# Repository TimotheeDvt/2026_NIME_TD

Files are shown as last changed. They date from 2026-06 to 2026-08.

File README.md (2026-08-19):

REMORA logo
# Remora - A Motion-Controlled Musical Instrument

**Remora** is a digital musical instrument built around a martial arts staff (bô) augmented with an IMU sensor. Physical gestures such as spinning, tilting, striking, sweeping are translated in real time into expressive audio synthesis. The name *NIME* in the codebase stands for **New Instrument for Musical Expression**, and reflects the instrument design philosophy.

The audio side ships as **REMORA** (*Real-time Expressive Motion to Output Routing Audio*), a JUCE plugin that turns the incoming motion stream into sound.

---

## Project Overview

The instrument consists of two parts:

**Firmware** - An ESP32-S2 microcontroller mounted on the staff reads a 9-DOF IMU (MPU-9250) at 100 Hz and streams orientation data (quaternion, accelerometer, gyroscope, magnetometer) over Wi-Fi as OSC packets.

**Software** - REMORA, a JUCE-based VST3/Standalone audio plugin, receives the OSC stream, applies a user-defined calibration, extracts musical parameters from the motion, and drives an internal additive synthesiser with multiple mapping strategies selectable at runtime.

The two communicate over a local Wi-Fi network using UDP/OSC on port 8000.

```
[ Bô Staff ]
  └─ MPU-9250 IMU
  └─ SparkFun ESP32-S2 Thing+
       │  Wi-Fi / UDP / OSC  (port 8000)
       ▼
[ Host Computer ]
  └─ REMORA Plugin (VST3 / Standalone)
       ├─ OscReceiverManager   - receives and parses packets
       ├─ REMORAProcessor      - calibration, quaternion maths
       ├─ BoStaffSynth         - 4-voice additive synthesiser
       └─ IMappingStrategy     - swappable gesture-to-sound mappings
```

---

## Repository Structure

```
.
├── firmware/               # PlatformIO project for the ESP32-S2
│   ├── README.md               # Board/wiring, build/flash steps, OSC wire protocol
│   ├── platformio.ini          # Board, platform, and library config
│   └── src/
│       └── main.cpp            # IMU read loop + OSC transmission
│
├── software/               # JUCE CMake project (VST3 + Standalone)
│   ├── CMakeLists.txt
│   ├── Makefile                # Convenience wrapper around CMake
│   ├── README.md                # Build/run steps, calibration, and a deep dive into every mapping strategy's DSP
│   ├── IDEAS.md                # Scratchpad of in-progress mapping ideas
│   ├── JUCE/                   # JUCE library (cloned locally, not tracked here)
│   ├── Assets/
│   │   └── logo.svg
│   └── Source/
│       ├── PluginProcessor.{h,cpp}   # REMORAProcessor: calibration, OSC bridge
│       ├── PluginEditor.{h,cpp}      # REMORAEditor: main UI
│       ├── DATA/
│       │   ├── IMUData.h             # Lock-free IMU data store (seqlock)
│       │   └── OrientationPoint.h    # Timestamped quaternion for trail rendering
│       ├── DSP/
│       │   ├── MathHelpers.h         # Quaternion / vector maths
│       │   ├── IMappingStrategy.h    # Abstract mapping interface
│       │   ├── BoStaffSynth.{h,cpp}  # 4-voice additive synth engine
│       │   └── Mappings/             # One class per mapping strategy (see below)
│       ├── OSC/
│       │   └── OscReceiverManager.{h,cpp} # JUCE OSCReceiver wrapper
│       └── UI/                       # Calibration overlay, raw-data/debug/DSP
│                                     # diagnostic windows, spectrum analyser, styling
├── hardware/
│   ├── README.md                         # Casing model, printing, and battery notes
│   ├── Assets/                           # Reference models for the ESP32 board and MPU chip
│   ├── PRINTABLE/                        # Exported STL/gcode ready to slice and print
│   ├── case_vscode.scad                  # Parametric casing model (OpenSCAD Customizer)
│   └── base_print.scad                   # Utility to export a flat cutting/drilling pattern
│
└── tests/                   # OSC + gesture-mapping prototyping and test tools
    ├── testOSCReceiver.py                    # Minimal Python OSC listener on port 8000
    ├── exploration_tests/                    # PyQt/matplotlib gesture-simulation sandbox
    ├── PlugData/                             # Pure Data patches + mock-data generator
    └── PurrData/Karplus-Strong/              # Karplus-Strong string synthesis patches
```

---

## Firmware

ESP32-S2 + MPU-9250 read loop, streaming orientation/motion data as OSC over Wi-Fi. See [`firmware/README.md`](firmware/README.md) for wiring, configuration, build/flash steps, and the full OSC wire protocol.

---

## Software

JUCE VST3/Standalone plugin with a visual node-graph mapping engine. See [`software/README.md`](software/README.md) for build steps, running the plugin, calibration, the Node Graph Editor, and a full technical breakdown of every mapping strategy (Simple, Bowed Chord, Lead + Drone, Spin Filter, Martial Effort/Momentum, Azimut and its variants, Speed Gate, Spin Voices).

---

## Hardware

Staff-mounted enclosure carrying the ESP32-S2, MPU-9250, and a 2000 mAh LiPo battery (charged over USB via the board's onboard circuit). See [`hardware/README.md`](hardware/README.md) for the casing model and battery notes.

---

## Credits

Instrument design, firmware, and software by **Timothée D.**.

Built with [JUCE](https://juce.com/), [PlatformIO](https://platformio.org/), [hideakitai/MPU9250](https://github.com/hideakitai/MPU9250), and [CNMAT/OSC](https://github.com/CNMAT/OSC).

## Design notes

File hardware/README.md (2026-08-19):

REMORA logo
# REMORA Hardware
### Real-time Expressive Motion to Output Routing Audio

The staff-mounted enclosure that carries the ESP32-S2, MPU-9250, and battery. See the [top-level README](../README.md) for how this fits into the full system, and [firmware/README.md](../firmware/README.md) for the electronics wiring (I2C pins, charging circuit) that this case is built around.

## Contents

```
hardware/
├── Assets/                # Reference STL models for the ESP32 board and MPU chip
├── PRINTABLE/              # Exported STL/gcode ready to slice and print
├── case_vscode.scad        # Parametric casing model (OpenSCAD Customizer)
├── base_print.scad         # Utility to export a flat cutting/drilling pattern
└── calibration_stand.scad  # Stand used for the plugin's three-pose calibration procedure
```

## Enclosure

`case_vscode.scad` is a parametric OpenSCAD model of the staff-mounted enclosure for the ESP32-S2, MPU-9250, and a 2000 mAh LiPo battery, closed with a strap-and-screw fit. Customizer variables live at the top of the file; `render_mode` switches between rendering the cap, the base, both, or neither for faster iteration.

`base_print.scad` projects the base down to a flat pattern for cutting/drilling references.

Ready-to-slice output lives in `PRINTABLE/` (`BASE.stl`, `CAP.stl`).

## Battery

The SparkFun ESP32-S2 Thing+ has an onboard LiPo charge circuit with a JST-PH connector: connect the battery to the board and USB charges it directly, so the only cable the performer needs between sets is for charging - no separate charger required. Battery runtime under REMORA's actual 100 Hz sampling load has not been measured yet.

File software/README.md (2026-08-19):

REMORA logo
# REMORA Plugin
### Real-time Expressive Motion to Output Routing Audio

A real-time, dynamic **JUCE-based audio application** engineered to receive incoming multi-sensor IMU data via **Open Sound Control (OSC)**. The software serves as a modular audio mapping engine, converting spatial movements and hardware interactions into complex sound synthesis.

## Core Features

* **Standalone Application:** Ships today as a standalone desktop app; JUCE's plugin formats (VST3, AU, ...) are just a `FORMATS` entry away in `CMakeLists.txt` if a hosted-in-a-DAW build is ever needed.
* **Visual Node Graph Editor:** Every mapping - built-in or your own - is a `NodeGraph`: a DAG of Source/Math/Sink nodes evaluated once per audio block. Open the DSP window's **Graph** tab to inspect, rewire, or build one from scratch on a live patching canvas, with instant audio feedback and no recompiling required.
* **Preset Management:** Create, save, and load node graphs as presets from a preset folder you configure once (via the **Options** button) and that persists across sessions - your own patches live right alongside the built-in mappings.
* **Integrated Synth Engine:** Features a built-in algorithmic synthesis framework (`BoStaffSynth`) designed specifically for performance interaction.
* **Visual Diagnostic Windows:** Includes dedicated GUI interfaces for viewing live raw IMU data streams, debugging console logs, and visually monitoring spatial movements.
* **Scalable Branding:** The editor header renders the REMORA logo from an embedded SVG (`Assets/logo.svg`), tinted to match the UI palette, so it stays crisp at any window size instead of scaling a bitmap.

---

## Building

### Prerequisites

- **CMake 3.22+**
- **Ninja** build system
- A C++17-capable compiler (MSVC 2022 on Windows, Clang/GCC on macOS/Linux)
- JUCE cloned as a subdirectory at `JUCE/`

  ```bash
  cd software
  git clone https://github.com/juce-framework/JUCE.git
  ```

### Steps

Using the provided `Makefile`:

```bash
cd software
make clean    # remove build directory
make          # configure + build
make build    # build only
```

Build artefacts are written to `build/REMORA_artefacts/Standalone/REMORA` - run directly, no DAW needed.

Only the `Standalone` format is built right now (see `FORMATS` in `CMakeLists.txt`). Adding `VST3` (or another JUCE plugin format) to that list and rebuilding is enough to get a loadable plugin alongside it - no other code changes required.

### Runtime Dependencies

The app is dynamically linked so you might need to install some system librairies:

```bash
# Debian/Ubuntu
sudo apt install libfontconfig1 libfreetype6 libasound2

# Arch
sudo pacman -S fontconfig freetype2 alsa-lib
```

`fontconfig`, `freetype2`, and `alsa-lib` (ALSA) are the ones most likely to be missing on a minimal install; the rest (libstdc++, libpng, zlib, ...) ship on virtually every desktop system.

---

## Running

1. Ensure the ESP32 is streaming to your machine (or use `../tests/testOSCReceiver.py` to verify packets are arriving on port 8000). See [firmware/README.md](../firmware/README.md) for flashing the board.
2. Launch the standalone app.
3. Click **CONNECT** to start the OSC receiver on port 8000.
4. Click **CALIBRATE** and follow the three-pose procedure below to align the sensor's local frame with musical space.
5. Select a mapping from the dropdown and move the staff. Use **RAW DATA**, **DEBUG**, and **DSP** to open the diagnostic windows if needed.

### Calibration

The plugin uses a three-pose calibration to build a correction quaternion that maps the sensor's arbitrary mounting orientation to a consistent musical frame:

1. **Pose A** - staff horizontal, pointing forward
2. **Pose B** - staff vertical, pointing up
3. **Pose C** - staff horizontal, pointing right

After recording all three poses the plugin computes an orthonormal rotation matrix via polar decomposition and converts it to a quaternion applied to every subsequent reading. This means the instrument behaves identically regardless of how the sensor is physically oriented or mounted on the staff.

---

## Node Graph Editor

At the heart of REMORA's mapping engine is a **visual, node-based patching system**. Instead of hardcoded mapping classes, every performance mapping - from the simplest pitch/roll patch to the full Azimut engine - is a `Graph::NodeGraph`: a directed acyclic graph of small typed nodes, wired together and re-evaluated once per audio block.

* **Node Categories:**
  * **Source nodes** read live sensor/motion data (raw IMU channels, or derived motion features like gyroscopic magnitude, Laban weight/time/space/flow, facing angle, spin count).
  * **Math nodes** transform values in between - scaling, quantizing to a scale, gating, smoothing, crossfading, and more.
  * **Sink nodes** write the final result into a synth parameter (pitch, gain, filter cutoff, drive, reverb send, etc.), and automatically get a live-value monitor knob in the DSP window.
* **Live Patching Canvas:** Right-click empty canvas to add a node, drag from an output pin to an input pin to connect, right-click a node to delete it, right-click a wire to disconnect it. Pan by dragging the background, zoom with the mouse wheel. Hovering a pin shows its current live output value.
* **Auto Layout:** One click tidies the whole graph into ranked columns (flow direction) and lanes (parallel branches), with adjustable **Rank Sep** / **Node Sep** spacing sliders.
* **Non-Destructive Editing:** Edits are tracked per-graph; a **Reset Changes** button reverts the currently open graph back to how it looked when it was last loaded or saved, so experimenting with a built-in preset is always safe to undo.
* **Preset Workflow:** The selector bar above the canvas manages presets directly:
  * **New** starts a blank graph under a name you choose.
  * **Save** writes the current graph back to its file;
  * **Load** lists every `.xml` preset found in your preset folder and opens the one you pick.
  * **Options** lets you point the preset folder at any location on disk - the choice is remembered across sessions.

Because every mapping in this project - including all of the ones documented below - is implemented as a graph, none of them are fixed in stone: open any preset in the Graph tab to see exactly how it works, tweak it, or use it as the starting point for your own.

---

## Performance Mapping Strategies

This technical section details how physical movements stream through each mapping's node graph and directly manipulate the parameters of the synthesizer engine. Nine presets are currently registered in `SynthManager`, in the order below - every one of them a `NodeGraph` you can open, study, and remix in the [Node Graph Editor](#node-graph-editor).

| Mapping | Core idea |
|---|---|
| **Simple (Pitch+Roll)** | Single sine wave. Pitch angle sets the root frequency, roll amount sets the volume - the most direct staff-to-pitch mapping. |
| **Wind Noise** | No pitch, no chord - just filtered noise. Gyro+accel energy swells and dies down like gusts of wind, opening the noise filter and master lowpass brighter the faster you move. |
| **Bowed Chord** | Pitch angle quantizes to a chromatic root; yaw and roll select the chord voicing. Gyro speed acts like bow pressure, driving volume/drive/brightness, and sharp jabs add a noise strike. |
| **Lead + Drone** | Tilt drives a major-scale melody. A 4-voice drone chord stays harmonically locked below it; yaw crossfades two drone voices. |
| **Martial Momentum** | Root note is one of four fixed pitches chosen by spin plane/direction, gliding at a rate set by spin momentum. Volume is gated by movement plus Laban "Weight" and thrust jabs. |
| **Azimut Kinetic** | Root note from spin plane, direction, and facing (north/south). A single rotation-speed value fans out to filter cutoff, brightness, drive, noise, vibrato/tremolo and reverb all at once. |
| **Speed Gate** | Speed-gated crossfade: a simple pentatonic melody below a speed threshold, the full Azimut Kinetic mapping above it, with no clicks at the transition. |
| **Spin Voices (Scale)** | Roll angle selects which of 4 independent voices is "live"; its pitch snaps to the nearest note of a major scale and glides, while the other voices hold their last pitch/gain. |
| **Vocal Tract** | A physically-modeled voice (glottal source + digital-waveguide vocal tract) instead of the additive engine. Pitch sets glottal pitch, roll/yaw shape the vowel, motion and Laban "Weight" drive volume/tenseness, thrust jabs pinch the tract for consonant-like bursts. |

> Older presets (`Spin Filter`, `Martial Effort`, `Azimut`, `Azimut+`, `Azimut Reverb`, plain `Spin Voices`) still exist as `Graph::Presets::build*()` functions but are commented out of `SynthManager`'s registration list, superseded by the entries above - see [`Source/DSP/SynthManager.cpp`](Source/DSP/SynthManager.cpp).

---

### 1. Simple Mapping

* **Movement Inputs:** Absolute pitch tilt, absolute roll.
* **DSP Transformation:**
  * **Pitch Tilt:** Linearly maps pitch angle onto a single voice's fundamental frequency (100 Hz - 1000 Hz).
  * **Roll Gate:** Absolute roll angle drives master volume (0.05 - 0.20), acting as a simple tilt-based dynamic gate. A single voice plays with no partials beyond the fundamental.

---

### 2. Bowed Chord Mapping

* **Movement Inputs:** Total Gyroscopic Velocity ($|Gyro|$), Absolute Yaw, Pitch, and Roll ($|\text{Roll}|$).
* **DSP Transformation:**
  * **Excitation (The Bow):** Synthesizer excitement and voice gains are scaled by gyroscopic magnitude above a floor of $12.0^\circ/\text{s}$. If the device stops, the sound dampens instantly.
  * **Chord Harmonization:** Yaw angle selects 1 of 4 chords. Tilting the device past an intense roll boundary ($>0.7\text{ rad}$) overrides the scale into secondary chord sets.
  * **Acoustic Friction & Strikes:** Linear acceleration changes ($\Delta Accel$) generate an impulse envelope ($0.9990$ decay half-life) triggering a physical modeling-style noise stroke. Absolute roll maps to vibrato depth and high Z-axis angular velocity adds dynamic tremolo.

---

### 3. Lead + Drone Mapping

* **Movement Inputs:** Absolute Pitch (lead melody), Absolute Yaw (drone balance), Linear Acceleration Magnitude, Gyroscopic Magnitude.
* **DSP Transformation:**
  * **Lead Voice:** Pitch is quantized to a Major scale spanning several octaves around A3 ($220\text{ Hz}$).
  * **Locked Drone Voices:** Three drone voices sit at fixed intervals below the lead (an octave, two octaves, and a fifth) but are transposed by the *same* amount as the lead root, so they stay harmonically locked to whichever scale degree is currently playing.
  * **Timbre & Swell:** Acceleration magnitude drives lead voice gain, drone "swell" (amplitude growth), drive amount, noise injection, and upper-partial brightness. Yaw crossfades gain and hard-pans the two side drone voices against each other.

---

### 4. Spin Filter Mapping

* **Movement Inputs:** Gyroscopic Magnitude, Pitch, Yaw, Roll, Linear Acceleration Magnitude.
* **DSP Transformation:**
  * **Quantized Steps:** Gyroscopic magnitude steps through a 5-note Pentatonic Scale (2 voices: root + perfect fifth), rooted at C3 ($130.81\text{ Hz}$).
  * **Roll as Brightness Ceiling:** Absolute roll acts as a movable low-pass "ceiling" over the 6 harmonic partials - as roll increases, partials progressively unmute with a one-partial-wide crossfade at the boundary, rather than a hard cutoff.
  * **Motion Energy:** Combined gyroscopic and acceleration energy drives master gain and noise amount; pitch drives vibrato depth and yaw drives stereo panning.

---

### 5. Martial Effort Mapping

* **Movement Inputs:** Laban Movement Analysis features (Weight, Time, Space, Flow), calculated from dynamic linear acceleration ($\text{Accel} - \text{Gravity}$) and angular differences.
* **DSP Transformation:**
  * **Quantized Note Steps:** Smoothed gyroscopic magnitude quantizes directly into a 5-note Pentatonic Minor Scale. Faster movement transitions step-wise higher up the scale.
  * **Harmonic Polyphony:** Laban Weight (integrated velocity from non-gravitational acceleration) dynamically calculates voice presence. Heavy, high-momentum gestures open up 4 concurrent polyphonic voices playing Major, Minor, 7th, or Diminished structures based on rotation plane axis (Vertical vs. Horizontal) and direction (CW vs. CCW).

---

### 6. Martial Momentum Mapping

Martial Momentum shifts the paradigm from scale-quantization to trajectory-driven momentum tracking and gesture triggers. It shares its Laban engine (weight/time/space/flow) with Martial Effort, but replaces scale-stepping with a spin-plane root note, a spin-count-driven filter sweep, and axial thrust detection. Its rotation-direction classifier resolves CW/CCW *relative to the direction first captured when the gesture began* rather than a true world-frame compass - that absolute-compass feature is what the **Azimut Mapping** below completes.

* **Root Note by Spin Plane + Direction:** The rotation axis is classified as Vertical or Horizontal, and CW/CCW relative to the first spin direction observed. This selects a fixed pitch class (C / E for Vertical CW / CCW, G / A for Horizontal CW / CCW) instead of scale steps, played as bare octaves and fifths rather than a full chord.
* **Continuous Rotational Velocity (Filter Sweep):** The mapping accumulates rotational degrees over time; every full $360^\circ$ loop increments `continuous_spin_count_`, resetting whenever the spin plane or direction changes. The spin count drives a phase modulator ($\text{Phase} = \text{Count} \times 1.5$), whose sine output sweeps a global Low-Pass Filter between $400\text{ Hz}$ and $20{,}000\text{ Hz}$.
* **Axial Thrust Detection:** Real-time zero-crossing jerk detection isolates sudden linear acceleration along the staff's longitudinal axis ($>1.5\text{ g}$) while gyroscopic magnitude stays low (below $90^\circ/\text{s}$, to exclude spins). Each validated thrust punches through the gain gate, boosts upper partials (3rd-5th) and drive amount, and injects a short burst of high-frequency noise.

---

## Deep Dive: Azimut Mapping

**Azimut** is the mapping that finishes what Martial Momentum started: instead of a relative CW/CCW reference, it computes a true world-frame **facing direction** and combines it with spin plane + spin direction for an 8-way root note table. It keeps V2's Laban engine, spin-count filter sweep, and axial thrust detection, and adds the facing axis on top. It ships in two flavors - `AzimutMapping` (`"Azimut"`) and a variant, `AzimutPlusMapping` (`"Azimut+"`) - described at the end of this section.

#### A. The Directional Angular Compass (Facing + Root Note Selection)

* **Reference Frame:** "Facing" is measured relative to the calibration gesture's own forward pose (virtual world $+X$ = North, $+Y$ = East), not magnetic north - the magnetometer is unreliable this close to the staff's own hardware and stage equipment.
* **Vertical-Plane Spins:** When the rotation axis is Vertical, the smoothed rotation axis itself is used as the facing vector. The horizontal domain is split into North/East with an $\approx1.15$ hysteresis ratio between the two axes ($\approx$ 48°/42° switch points) to stop the root note flickering near the boundary.
* **Horizontal-Plane Spins:** Facing instead tracks the staff's own long axis (smoothed tip direction) in world space — but as the table below shows, the root note only ends up depending on spin direction here, not facing.

| Spin Plane | Spin Direction | Facing | Root Note | Semitones |
|---|---|---|---|---|
| Vertical | CW  | North | **C** | 0 |
| Vertical | CW  | East  | **G** | +7 |
| Vertical | CCW | North | **E** | +4 |
| Vertical | CCW | East  | **B** | +11  |
| Horizontal | CW  | - | **G** | +7 |
| Horizontal | CCW | -  | **A** | +9 |
* **Morphing:** The target root note morphs to the current one via a one-pole filter whose speed scales with staff speed, with an extra boost right after the staff leaves rest so the pitch snaps to the new root quickly instead of crawling into it.
* **Voicing:** Rather than a chord, only octaves and a fifth are layered on the root (`[+12, +7, -12]` semitones) to preserve the pitch class.

#### B. Continuous Rotational Velocity (The Filter Modulation Sweep)

* **Movement:** Accumulated rotational degrees are tracked over time (independent of facing). Every full $360^\circ$ loop increments a persistent `continuous_spin_count_`; the counter (and accumulated degrees) reset instantly whenever the spin plane or spin direction changes.
* **DSP Result:** The spin count feeds an active phase modulator: $\text{Phase} = \text{Count} \times 1.5$. The resulting sine wave drives a global **Low-Pass Filter sweep** between **$400\text{ Hz}$** and **$20{,}000\text{ Hz}$**. Continuous physical spinning in one direction produces a cyclic timbral wave effect.

#### C. Axial Thrust Detection (Transient Punches)

* **Movement:** Dynamic linear acceleration is rotated into world space and projected onto the staff's own long axis; a signed zero-crossing jerk detector flags a peak once the axial acceleration exceeds $1.5\text{ g}$, gated to gyroscopic magnitude below $90^\circ/\text{s}$ so spins aren't mistaken for stabs, and rate-limited by a 200 ms cooldown.
* **DSP Result:** Each validated thrust fires a fast-decaying impulse ($\approx150\text{ ms}$ half-life) that simultaneously:
  * **Gain Envelope Boost:** Punches through the master gain gate.
  * **Harmonic Waveshaping & Distortion:** Boosts `driveAmt` and injects energy into upper partials 3-5, pushing the tone from a clean fundamental into a sharp, growling distortion.
  * **High-Frequency White Noise Injection:** Releases a brief, unpitched high-frequency noise burst (`noiseAmount`), giving the strike a percussive edge.

#### Azimut+ Variant

`AzimutPlusMapping` reuses the exact same body-motion engine (Laban weight/time/space/flow, facing, thrust detection) as Azimut, with one change: the Low-Pass Filter cutoff tracks the staff's **instantaneous rotation speed** directly (linearly mapped from the $30^\circ/\text{s}$ floor to the $750^\circ/\text{s}$ ceiling, 400 Hz-20 kHz) instead of the accumulated spin count from section B. This trades the cyclic sweep-per-loop character of Azimut for a filter that opens and closes continuously with how fast the performer is currently moving.

#### Azimut Reverb Variant

`AzimutReverbMapping` reuses the exact same body-motion engine as Azimut (facing, spin-count filter sweep, thrust detection, section A-C above are unchanged), with one change: Laban Flow - computed every block but discarded via `ignoreUnused` in Azimut and Azimut+ - now drives a reverb send.

* **Flow → Reverb Send:** `flow_free` (loose, unrestrained motion; the complement of `flow_bound`, see the Laban Flow definition in section B) sets the wet level, scaled by Laban Weight so a loose but tiny gesture doesn't flood the sound: $\text{wetLevel} = \text{flow\_free} \times (0.25 + \text{weight} \times 0.75)$, clamped to $[0, 1]$.
* **Flow → Room Size / Damping:** the same `flow_free` also maps linearly to the reverb's room size ($0.25 \rightarrow 0.95$, i.e. decay length / "feedback") and inversely to its damping ($0.80 \rightarrow 0.15$, i.e. high-frequency absorption). Free, loose motion therefore opens a longer, brighter tail; bound, tense motion collapses it back toward a short, damped, near-dry space.
* **DSP Implementation:** `BoStaffSynth` owns a single shared `juce::dsp::Reverb` instance, gated by `MappingOutput::reverbWetLevel/reverbRoomSize/reverbDamping`. The wet level is smoothed over 50 ms and the wet/dry mix is done manually per sample (rather than via the Reverb's own internal wet/dry parameters) so switching mappings, or Flow itself swinging quickly, never zippers. `BoStaffSynth` resets `reverbWetLevel` to 0 before calling into whichever mapping is active, so only Azimut Reverb ever turns the send on - every other mapping stays untouched and fully dry.

---

### Speed Gate Mapping

A speed-gated crossfade between a simple melody and the full Azimut engine, so slow, deliberate gestures and fast, dynamic ones each get a purpose-built sound.

* **Below the Gate ($<120^\circ/\text{s}$):** A simple melody plays - pitch is quantized to a Major Pentatonic scale across 2 octaves, roll drives master gain, and yaw pans the voice across the stereo field.
* **Above the Gate ($>180^\circ/\text{s}$):** The full Azimut Mapping (facing + spin plane/direction root selection, filter sweep, thrust detection) takes over completely.
* **The Crossfade:** Between $120^\circ/\text{s}$ and $180^\circ/\text{s}$ (a $60^\circ/\text{s}$ band centered on a $150^\circ/\text{s}$ gate), every output parameter - pitch, gains, timbre, panning, filter cutoff - is linearly interpolated between the two mappings' outputs, so crossing the threshold never clicks.

---

### Spin Voices Mapping

Builds a sustained chord one note at a time by letting spin state "freeze" voices in place.

* **Movement:** Spin plane (Vertical/Horizontal) and spin direction (CW/CCW) select 1 of 4 controllable voices, each permanently assigned to one combo (CW+Vertical, CCW+Vertical, CW+Horizontal, CCW+Horizontal). Facing is deliberately not part of this mapping.
* **DSP Result:** Only the currently active voice updates each frame - its pitch bends upward from its base chord tone (a C major arpeggio across two octaves: `[0, 7, 12, 19]` semitones) by up to +12 semitones with staff speed, and its gain follows Laban Weight. The other three voices hold their last pitch and gain exactly where they were left. Master gain is fixed at 1.0, so the chord stays sustained even at rest - moving through all 4 spin combos in sequence builds up the full chord note by note.

---

## Project Context

This software component is a core part of the larger **timotheedvt/2026_nime_td** ecosystem. It bridges the gap between hardware physical controllers and modern digital audio workstations.

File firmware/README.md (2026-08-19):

REMORA logo
# REMORA Firmware
### Real-time Expressive Motion to Output Routing Audio

PlatformIO project for the staff-mounted microcontroller. It reads the IMU over I2C and streams orientation data to the host computer over Wi-Fi/OSC for the REMORA plugin (see the [top-level README](../README.md) for the full system picture).

## Hardware

| Part | Role |
|---|---|
| [SparkFun ESP32-S2 Thing Plus](https://www.sparkfun.com/sparkfun-thing-plus-esp32-s2-wroom.html) | Microcontroller, Wi-Fi, onboard LiPo charge circuit |
| MPU-9250 | 9-DOF IMU (accelerometer, gyroscope, magnetometer), wired over I2C |
| 2000 mAh LiPo battery | Powers the unit via the Thing Plus's JST-PH connector |

- I2C: SDA = GPIO 1, SCL = GPIO 2 (`Wire.begin(1, 2)` in `src/main.cpp`), 400 kHz clock.
- MPU-9250 I2C address: `0x68`.
- GPIO 13 drives the board's blue STAT LED: blinking while attempting to connect to Wi-Fi, solid once connected.
- Charging: plug the LiPo into the Thing Plus's JST connector, then power the board over USB. The onboard charge IC handles charging automatically - no separate charger needed. Battery runtime under the firmware's steady 100 Hz sampling rate has not been measured yet.

## Prerequisites

- [PlatformIO](https://platformio.org/) (CLI or the VS Code extension)
- SparkFun ESP32-S2 Thing Plus connected over USB

## Configuration

Before flashing, edit the network settings at the top of `src/main.cpp`:

```cpp
const char *WIFI_SSID     = "YOUR_SSID";
const char *WIFI_PASSWORD = "YOUR_PASSWORD";
const IPAddress outIp(192, 168, 12, 1); // host machine running the REMORA plugin
```

These are compiled into the firmware (there's no runtime config), so a new venue or a new host IP means editing this file and reflashing. `src/main.cpp` currently has real credentials checked into the repo history - swap them for your own network before flashing, and avoid committing real credentials again since this repo is public.

## Build / Flash / Monitor

```bash
cd firmware
pio run                        # build only
pio run --target upload        # build + flash
pio device monitor --baud 115200
```

The PlatformIO environment is `sparkfun_esp32s2_thing_plus` (see `platformio.ini`). On boot the board prints its assigned IP and confirms it is streaming.

## Dependencies

Declared in `platformio.ini`:

- [hideakitai/MPU9250](https://github.com/hideakitai/MPU9250) - IMU driver, also computes the fused quaternion
- [CNMAT/OSC](https://github.com/CNMAT/OSC) - OSC message construction

## Wire Protocol

UDP/OSC, sent from the board to `outIp:8000` (the host running the REMORA plugin); the board itself listens locally on port `8888`.

| Address | Args | Sent |
|---|---|---|
| `/esp32/connected` | `<ip:string>` | Once, right after Wi-Fi connects |
| `/esp32/imu` | `ax ay az gx gy gz mx my mz qw qx qy qz <ip:string>` (12 floats + string) | Every 10 ms (100 Hz), while `mpu.update()` has fresh data |

`ax/ay/az` = accelerometer, `gx/gy/gz` = gyroscope, `mx/my/mz` = magnetometer, `qw/qx/qy/qz` = the fused orientation quaternion computed onboard by the MPU9250 library.

If Wi-Fi drops mid-run, `loop()` detects it, halts sending, and blocks on reconnection before resuming the stream.

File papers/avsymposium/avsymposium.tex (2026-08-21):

\UseRawInputEncoding
\documentclass[a4paper,10pt,oneside]{article}
\usepackage{avs,amsmath,epsfig,times,url,hyperref,balance,float,booktabs,placeins,tikz}
\usetikzlibrary{positioning,arrows.meta}

\newcommand{\preset}[1]{\textit{#1}}

\title{REMORA: Real-time Expressive Motion to Output Routing Audio}
\subtitle{A Martial Arts Staff Instrument Driven by Motion}

\twoauthors
{\authorblock{Timoth\'ee Dravet}{Polytech Marseille, Aix-Marseille Universit\'e \\ Marseille, France \\ \email{timothee.dravet@etu.univ-amu.fr}}}
{\authorblock{Daniel Overholt}{CREATE, Aalborg University \\ Aalborg, Denmark \\ \email{dano@create.aau.dk}}}

\begin{document}
\ninept
\maketitle

\begin{sloppy}

\begin{abstract}
REMORA turns a b\^o, the long staff used in martial arts, into a musical instrument:
spins, tilts, and strikes become sound in real time. The instrument is built in two
parts: a small wireless sensor unit rides on the staff and continuously reads its
physical motion, while a companion audio plugin turns that motion into pitch, texture,
and timbre across three very different synthesis voices, from a warm additive choir to a
breath-driven vocal tract. Rather than one fixed gesture-to-sound behaviour, every
mapping from physical motion to sound parameters is a small patch of connected building
blocks - motion sources, shaping math, and synthesis sinks - wired on a visual canvas
inside the plugin, in the spirit of a modular synthesiser's patch cables. The same small
vocabulary of building blocks stretches from a beginner's direct tilt-controlled pitch to
a compound, deliberately one-to-many mapping whose timbre quietly re-randomises itself
with every completed spin, so that no two passes through the same gesture sound quite
identical. Nine such presets currently ship, pared down over the course of development
from a larger, more repetitive set of fifteen.
\end{abstract}

\section{Introduction}
\label{sec:intro}

REMORA grew out of the first author's parallel practice in martial arts and music. The
b\^o itself is a form largely absent from new interfaces for musical expression: a
full-body, two-handed, swung staff with its own weight, reach, and rotational inertia,
quite unlike the small handheld or body-worn sensors most inertial digital instruments
use. Where a martial artist reads speed, force, and reach off the staff by feel, REMORA
reads the same qualities electronically and turns them into sound: a spin becomes a
filter sweep, a slow controlled turn sounds
nothing like a fast, loose one. The instrument's vocabulary is, in that sense, borrowed
directly from the performer's own body of practice rather than invented for the
occasion. Crucially, that vocabulary is not baked into compiled code either: every
motion-to-sound relationship lives inside the plugin as a small, rewireable patch, so
extending or retuning it is an editing operation the performer or instrument-builder can
perform on the same canvas used to play the instrument, rather than a recompile.

Rod-, staff-, and baton-shaped controllers already form a small, recurring family in
this space: the T-Stick's touch-sensitive shaft~\cite{malloch2007tstick}, the Digital
Baton's conducting gesture~\cite{marrin1997digitalbaton}, and Nam's swung Musical
Poi~\cite{nam2013mpoi} among them. What REMORA adds to that family is less a new sensor
than a new relationship: a martial artist's years of staff-handling skill, carried
straight onto a stage as a musical vocabulary. The remainder of this paper describes how
that relationship is built, from the sensor unit on the staff (\S\ref{sec:system})
through the motion-to-sound mapping layer (\S\ref{sec:mapping}) to the resulting catalog
of presets (\S\ref{sec:presets}).

\section{System Design}
\label{sec:system}

\begin{figure}[H]
\centering
\begin{minipage}[c]{0.4\linewidth}
  \centering
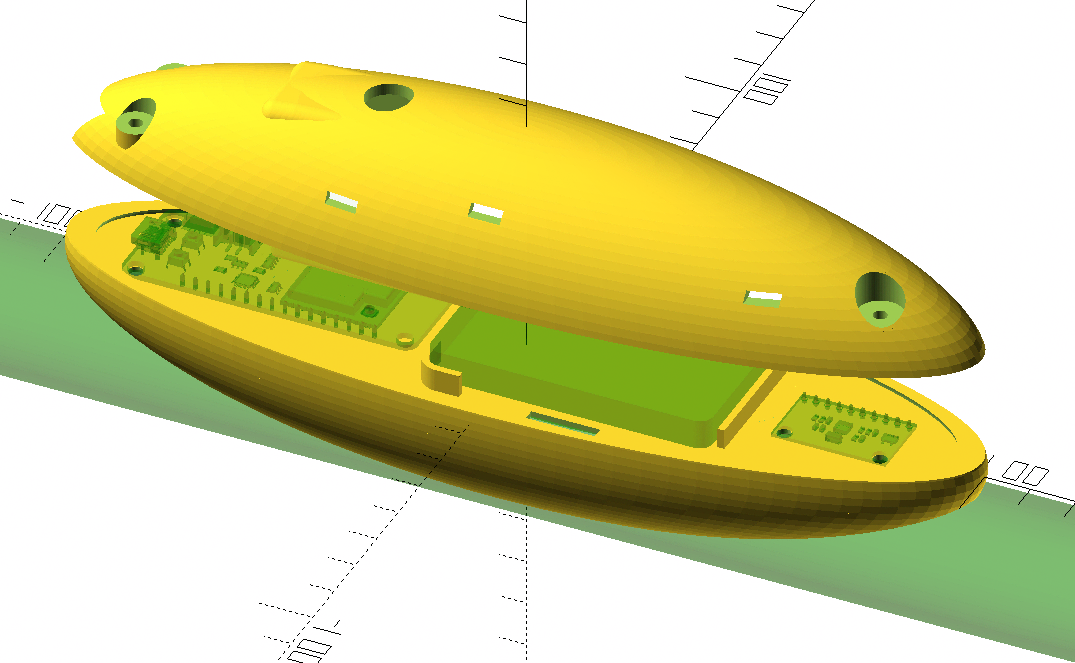
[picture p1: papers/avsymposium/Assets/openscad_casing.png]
  
  \centerline{(a)}
\end{minipage}
\hspace{4mm}
\hfill
\begin{minipage}[c]{0.4\linewidth}
  \centering
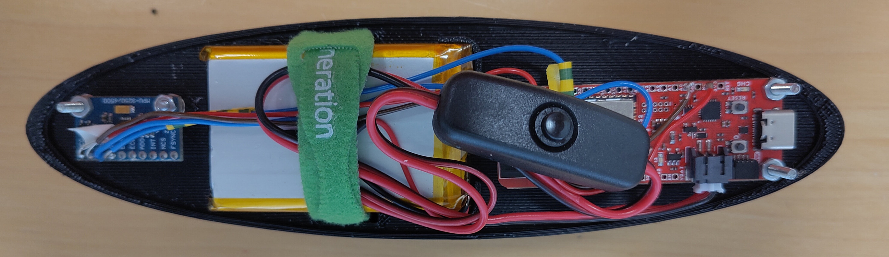
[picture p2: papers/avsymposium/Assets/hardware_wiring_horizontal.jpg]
  
  \centerline{(b)}\\[1mm]
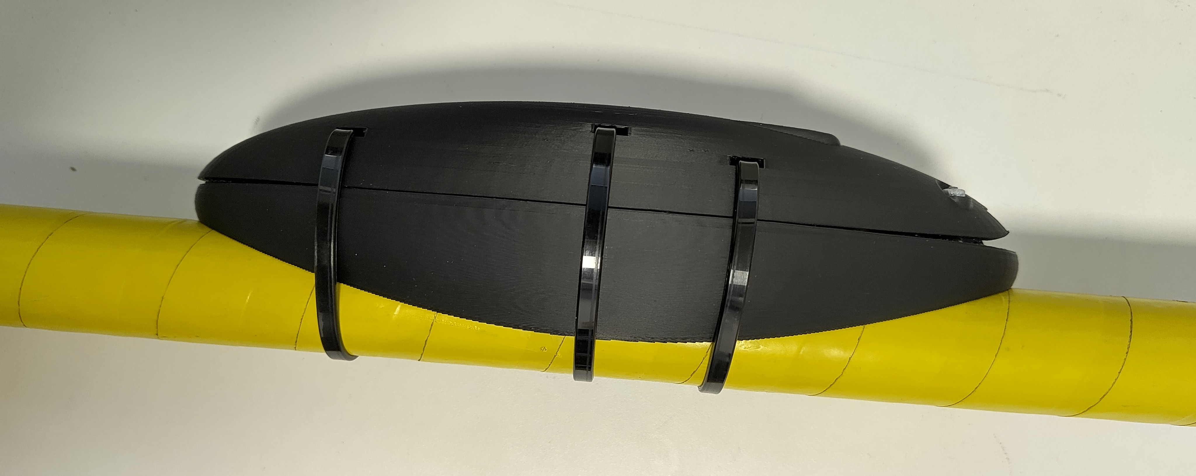
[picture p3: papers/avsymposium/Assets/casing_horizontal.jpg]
  
  \centerline{(c)}
\end{minipage}
\caption{The staff-mounted sensor unit, held on with zip ties so it can be repositioned
or removed without marking the staff: (a) the parametric OpenSCAD design; (b) the harware wiring; (c) the
printed enclosure zip-tied to the b\^o.}
\label{fig:enclosure}
\end{figure}

\begin{figure}[H]
\centering
\resizebox{\linewidth}{!}{%
\begin{tikzpicture}[
  box/.style={draw, rounded corners, align=center, text width=2.1cm, minimum height=0.55cm,
    font=\small\bfseries, inner sep=2pt},
  sub/.style={draw, align=center, text width=1.9cm, minimum height=0.45cm, font=\scriptsize,
    inner sep=1.5pt},
  arr/.style={-{Latex[length=1.5mm]}}
]
\node[box] (staff) {Firmware};
\node[sub, below=0.6mm of staff] (collect) {IMU sampling};
\node[sub, below=0.8mm of collect] (send) {OSC transmission};
\draw[arr] (collect) -- (send);

\node[box, right=26mm of staff] (host) {REMORA plugin};
\draw[arr] (staff) -- (host)
  node[midway, above, font=\scriptsize, align=center] {Wi-Fi / UDP / OSC};

\node[sub, below=0.6mm of host, xshift=-1.03cm] (recv) {OSC reception};
\node[sub, right=1.5mm of recv] (calib) {Calibration};
\draw[arr] (recv) -- (calib);
\node[sub, below=2mm of calib] (graph) {Graph evaluation};
\node[sub, below=2mm of recv] (synth) {Synthesis};
\draw[arr] (calib) -- (graph);
\draw[arr] (graph) -- (synth);
\end{tikzpicture}%
}
\caption{Signal path from staff motion to sound: the sensor unit streams orientation
  and inertial data over Wi-Fi to the plugin, which calibrates, derives motion
  qualities, and routes them through a performer-authored patch into one of three
  synthesis engines.}
\label{fig:architecture}
\end{figure}
\FloatBarrier

\subsection{Hardware}
\label{ssec:hardware}

Inside the enclosure shown in Figure~\ref{fig:enclosure}, a SparkFun ESP32-S2 Thing Plus
microcontroller reads a nine-degrees-of-freedom MPU-9250 inertial sensor over I2C and
packs orientation, acceleration, and gyroscope readings into an OSC packet, sent over
UDP at 100~Hz across the microcontroller's own connection to the host computer's Wi-Fi
hotspot. Joining the host's own hotspot rather than a dedicated access point keeps
pairing to a single step, at the cost of a Wi-Fi network name, password, and destination
address that are presently compiled into the firmware rather than set at runtime. Nothing
tethers the performer to a fixed point on stage; a cable is needed only to charge the
unit between sets.

\subsection{Calibration}
\label{ssec:calibration}

Because the sensor can be glued to the staff at any angle (exact placement is never
perfectly reproducible by hand, and often changes from one build of the enclosure to
the next), the plugin calibrates itself the first time the staff is held through three
reference poses. All three poses together fix which physical axis is functioning as
``forward'': the plugin scores every candidate axis by how close to mutually orthogonal
its direction turns out across the three poses, and keeps whichever axis comes closest.
The first two poses then resolve any leftover twist around that axis, by solving for the
small rotation that best lines up the measured forward/up directions with the
instrument's own ideal frame. From then on, the same instrument logic runs correctly no
matter where on the staff the sensor happens to sit, so a performer can move it without
re-learning the instrument underneath.

\subsection{Connection Robustness}
\label{ssec:robustness}

Two recent changes tightened the path from a sensor packet to audible sound. First, the
plugin now treats the incoming stream as stale after 150~ms without a fresh packet,
rather than the previous 500~ms, so a real Wi-Fi dropout is caught and muted noticeably
sooner. Second, that mute no longer shares a single ramp with normal playing: losing the
signal now fades the master gain out over 120~ms (long enough to avoid an audible click)
while recovering it fades back in over a much shorter 10~ms, so the instrument goes
quiet gracefully on dropout but comes back almost immediately once the connection
returns.

\section{Mapping Design}
\label{sec:mapping}

\subsection{Motion Qualities}
\label{ssec:qualities}

Every packet from the sensor is read against a moving reference: not just where the
staff is, but how it got there. Four continuous qualities borrowed from Laban Movement
Analysis are extracted from the motion stream every audio block. How forcefully the
staff moves becomes Weight, read from a leaky integral of its acceleration once gravity
is subtracted out, and typically driving loudness or waveshaping. How suddenly a spin
speeds up or stops becomes Time, driving attack speed and how quickly a chord change
lands. Whether the staff keeps spinning around the same axis or wanders becomes Space, a
timbral focus that tightens or loosens a filter or a chorus spread. How bound or free
the motion is becomes Flow, crossfading between a controlled and a freer, noisier
version of the same sound. Tilt and roll bend pitch and blend voices continuously; a
spin's lap count sweeps a filter cutoff along a slow curve; a stab or strike, a sharp
reversal in the staff-tip's acceleration, triggers a transient, a chord change, or a
percussive burst.

\subsection{Visual Patching}
\label{ssec:patching}

None of the relationships described above is a single fixed algorithm baked into
compiled code. Every one of them is authored as a small patch of connected building
blocks inside the plugin, on a visual canvas in the lineage of
Max~\cite{puckette1988patcher} and Pure Data~\cite{puckette1996puredata}, closer in feel
to the boxes-and-cables idiom that community modular-synthesis software such as VCV
Rack~\cite{belt2017vcvrack} carries over from hardware Eurorack patching than to a
conventional plugin's fixed control panel. Three functional kinds of node populate that
canvas: \emph{sources} (the raw sensor axes and the derived Laban qualities above),
\emph{math} (arithmetic; shaping curves such as range-mapping, logarithmic range-mapping,
clamping, crossfading, and scale-quantizing; lookup tables; and a handful of stateful
primitives - one-pole smoothers, leaky integrators, derivative detectors, hysteresis
gates, and a pseudo-random sample-and-hold), and \emph{sinks} (the exposed parameters of
whichever synthesis voice the patch is driving). A fourth kind, \emph{display}, carries
no signal of its own: a numeric readout, a level meter, and a scrolling scope can be
dropped inline on any wire purely to watch its live value, without altering the patch. A
patch is a directed graph with no cycles
allowed: the plugin topologically sorts it once whenever a wire changes, then re-walks
that fixed order once per audio block, so dragging in a node or dropping a new
connection mid-performance never forces the audio thread to replan anything. A named
preset is nothing more than one such graph, serialised to an XML file and reloaded by
name - the same mechanism a performer's own live patch is saved through, so a
custom mapping built during a rehearsal is stored no differently from a factory one.

That shared vocabulary is small enough to describe in full, yet stretches from the
simplest mapping in the catalog to a considerably more elaborate one. \preset{Simple}
is close to the shortest patch the graph can express: the pitch source feeds one
range-mapping node that becomes the root frequency (wired straight into the additive
voice's sink), and the roll source feeds an absolute-value node into a second
range-mapping node that becomes the gain (wired into its own, separate gain sink) - two
motion sources and three math nodes feeding two sink nodes in total, wired once and left
alone for the rest of the performance. \preset{Azimut Kinetic} sits at the other end of
the same vocabulary. Its
pitch and gain follow the same lookup-table-driven facing logic as the rest of the
Azimut family, but its timbre is deliberately one-to-many~\cite{hunt2002mapping}: a
single smoothed rotation-speed value fans out simultaneously into the filter cutoff,
harmonic brightness, waveshaping drive, noise amount, vibrato and tremolo depth, and
reverb send, so a spin sounds progressively buzzier, noisier, and more reverberant the
faster it turns, rather than moving one parameter in isolation. Layered on top of that
energy value, a derivative node watches the continuous spin-lap counter for the instant
each full rotation completes and fires a one-block pulse into a sample-and-hold node,
which then latches four fresh pseudo-random values; each value is chased by its own slow
one-pole ``drift channel'' - closing roughly 5\% of the remaining distance to its new
random target on every audio block, so the drift glides rather than jumps - and folded
back, in a small proportion, onto the cutoff, drive, noise amount, and harmonic
brightness the energy value already set.
The result is a mapping that never quite repeats itself: two visually identical spins
land on two different, nearby timbres, because every completed rotation quietly
re-rolls where the tone drifts to next - an instability the graph's existing math nodes
are enough to build, with no bespoke code and no audio-thread cost beyond four extra
smoothers.

\begin{figure}[t]
  \centering
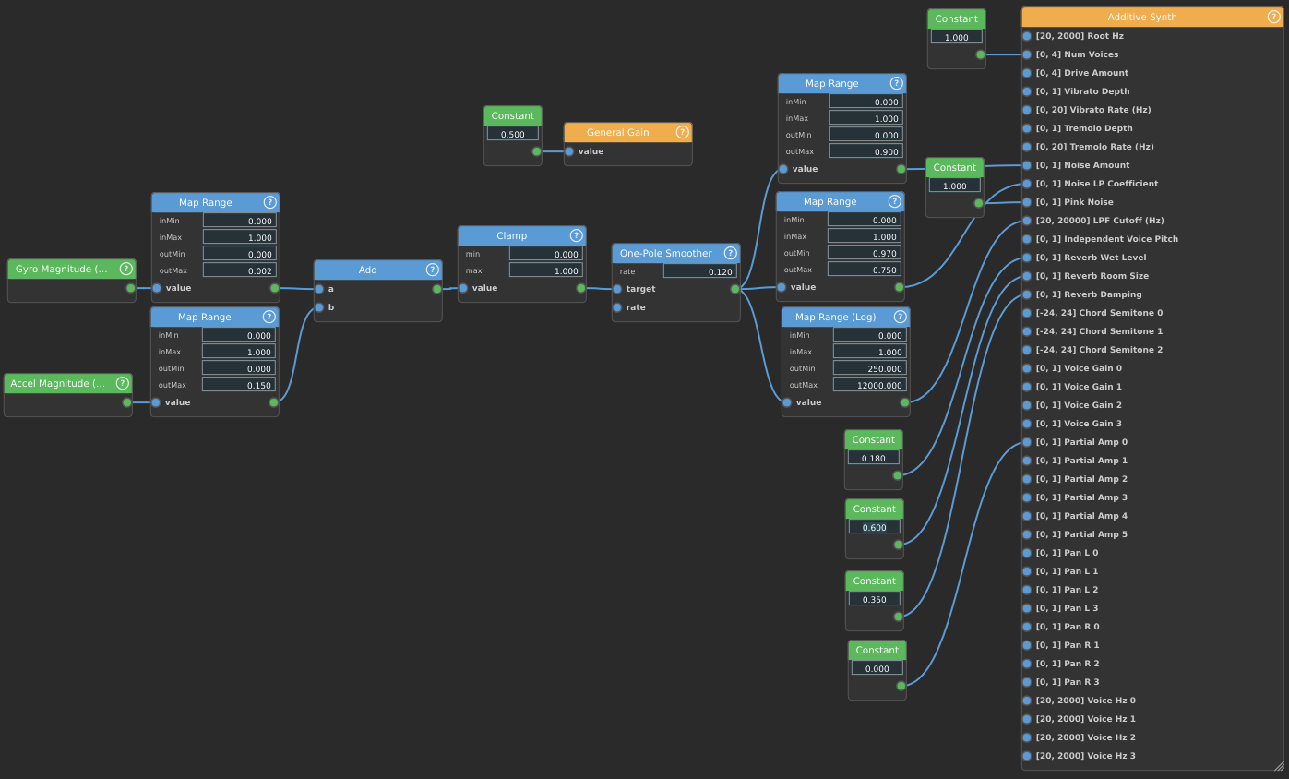
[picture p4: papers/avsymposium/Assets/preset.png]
  
  \caption{The \preset{Wind Noise} preset, seen inside the plugin: motion sources
  (green) - gyroscope and accelerometer magnitude - run through shaping and smoothing
  math (blue) into the exposed parameters of the additive-synthesis voice (orange).
  There is no pitch input anywhere in this patch: only motion energy, shaping noise
  amount and the master filter cutoff.}
  \label{fig:preset}
\end{figure}
\FloatBarrier

\subsection{Synthesis Engines}
\label{ssec:engines}

What a patch's output actually sounds like depends on which of three synthesis voices
its sink nodes are wired into. A default additive engine sums four voices of six
phase-locked harmonics each, vibrato- and chorus-detuned into a warm, faintly unstable
choir that a mapping can drive into a rasping saturation or filter down to a single dark
hum; a short comb resonator gives every voice a string-like colouration. That same engine
also carries its own built-in noise generator and filter, and it is this path, not a
separate voice, that \preset{Wind Noise} actually drives (Figure~\ref{fig:preset}): the
patch wires nothing at all into the engine's pitch inputs, only motion-energy-shaped
noise and filter cutoff, for a windy, textural character with no fixed pitch centre at
all. A second, granular engine sits alongside the additive one, synthesising its own
two-second bed of shifting harmonics and filtered noise and scattering up to 64
overlapping grains across it (forward, backward, panned, re-pitched); it is fully
implemented but not yet wired into any preset in the current catalog, so it stays silent
until a future patch calls on it. A third engine ports Neil Thapen's \emph{Pink
Trombone}~\cite{thapen2017pinktrombone}, a digital-waveguide vocal tract excited by a
glottal-pulse model and breathed into with filtered noise, so the instrument can also
simply speak, or half-speak, rather than only sing - the one engine with a preset built
specifically around it, \preset{Vocal Tract}. An engine a patch never wires into is
skipped entirely for that block, so presets built on one voice never pay for the other
two.

\section{Preset Vocabulary}
\label{sec:presets}

Nine named presets currently ship with the instrument (Table~\ref{tab:presets}), graded
by the physical vocabulary they ask of a performer rather than uniform in difficulty.
\preset{Simple} asks only for basic tilt and roll, an easy way in that needs no martial
background at all. The \preset{Azimut} and \preset{Martial} families reward the
staff-handling skill a martial artist already carries onto a stage: they derive a facing
direction and a spin quality straight from the calibrated motion stream, without ever
touching a magnetometer (which a stage rig's own electronics would only confuse), so
that where the staff points and how it turns becomes part of the music. \preset{Wind
Noise} trades pitch for a breathy, filtered-noise texture sustained by nothing but
motion; \preset{Vocal Tract} pushes the same sensor stream into something closer to a
voice than a synthesiser. Each preset is less a separate program than a different
character the same instrument can take on, chosen for a set the way a performer chooses
which piece to play next, rather than a fixed, single-piece score.

\begin{table}[t]
\centering
\small
\begin{tabular}{@{}p{0.32\linewidth}p{0.58\linewidth}@{}}
\toprule
Preset & Character \\
\midrule
\preset{Simple} & Pitch from tilt, volume from roll; one plain sine voice. \\
\preset{Wind Noise} & No pitch; motion energy swells filtered noise into gusts. \\
\preset{Bowed Chord} & Chromatic root from pitch; yaw/roll pick the chord; spin speed drives it like bow pressure. \\
\preset{Lead + Drone} & Major-scale lead over a 4-voice drone; yaw crossfades two drone voices. \\
\preset{Martial Momentum} & Root from spin plane/direction; glide speed set by spin momentum. \\
\preset{Azimut Kinetic} & Facing-based root; a single rotation-speed value drives filter, drive, noise, and reverb at once, with per-rotation stochastic drift. \\
\preset{Speed Gate} & Slow: pentatonic melody. Fast: crossfades into the Azimut facing/spin-based root and filter mapping. \\
\preset{Spin Voices (Scale)} & Roll picks 1 of 4 scale-quantized voices; the rest hold their last pitch/gain. \\
\preset{Vocal Tract} & Physically-modeled voice; pitch/roll/yaw shape glottal pitch and vowel; jabs add consonant-like bursts. \\
\bottomrule
\end{tabular}
\caption{The nine presets currently shipping, in load order.}
\label{tab:presets}
\end{table}
\FloatBarrier

This catalog is smaller than it once was. Fifteen mappings were implemented over the
course of development, but several turned out to be near-duplicates of one another once
built - a plain spin-driven pentatonic melody and its Laban-shifted cousin, three
separate Azimut variants that each added one extra timbral trick (a spin-count filter
sweep, a speed-tracking filter, a motion-driven reverb) on top of an otherwise identical
mapping. Rather than ship all fifteen, the list was pruned to nine: \preset{Azimut
Kinetic} folds every one of those three Azimut timbral tricks into a single one-to-many
mapping (\S\ref{sec:mapping}) instead of shipping them as separate, thinner presets, and
similar consolidations retired the redundant spin- and momentum-only mappings. The six
retired mappings still exist as graphs in the source tree - useful engineering reference
points and starting patches to fork from - but are no longer surfaced in the plugin's
own preset selector.

\section{Evaluation}
\label{sec:evaluation}

Ten performers with no prior exposure to REMORA (N=10) tried the instrument in a short,
informal pilot session: each was calibrated (\S\ref{ssec:calibration}), given a brief
demonstration, then played freely across a subset of the nine presets before completing
a short questionnaire. Their backgrounds were, by design, uneven: self-rated
martial-arts or staff-handling experience skewed low (nine of ten at 1 or 2 out of 5),
general music experience moderate, and prior experience with motion-controlled
instruments mixed - a pool weighted toward newcomers to the staff form itself, the
audience \preset{Simple} was designed to admit (\S\ref{sec:presets}).

Six statements about the playing experience, each rated on a five-point scale, are
summarised in Table~\ref{tab:eval}. Comfort scored highest and most consistently: the
enclosure and staff form factor did not get in the way of play. Novelty and absorption in
the music rather than the mechanics followed closely, suggesting the
motion-to-sound vocabulary reads as expressive enough to disappear behind, even in a
short first session. Predictability of the mapping and felt expressiveness scored lower
and more variably, consistent with the free-text feedback below: several participants
could point to specific gestures whose effect on the sound they could not reliably
predict.

\begin{table}[H]
\centering
\small
\begin{tabular}{@{}lc@{}}
\toprule
Statement & Mean (SD) \\
\midrule
Predictability & 3.4 (1.2) \\
Comfort & 4.0 (1.0) \\
Novelty & 3.9 (0.9) \\
Expressiveness & 3.3 (1.2) \\
Absorption & 3.9 (0.9) \\
Musical satisfaction & 3.6 (1.3) \\
\bottomrule
\end{tabular}
\caption{Mean (SD) agreement, 1--5 scale, N=10, on six playing-experience statements from
the post-session questionnaire.}
\label{tab:eval}
\end{table}
\FloatBarrier

Preference across presets split unevenly rather than converging on one: \preset{Azimut
Kinetic} was the most-picked (3/10), followed by \preset{Wind Noise} and \preset{Lead +
Drone} (2/10 each), with \preset{Spin Voices} and \preset{Vocal Tract} picked once each and
one participant declining to single one out (``all of them are great''). The reasons given
tracked each preset's intended character: \preset{Azimut Kinetic} for matching lived
martial-arts habit (``It matches best what I know from my martial art experience''),
\preset{Wind Noise} for needing no music or martial background at all (``just pure
instinct and simple movements''), \preset{Lead + Drone} for being the easiest to steer a
melody with while still sounding grounded.

The clearest actionable finding was not something we asked about directly. Three of ten
participants raised the same limitation unprompted, in three different free-text answers:
a striking or thrusting motion that felt physically decisive registered no equivalent
change in the sound (``Occasional frustration when a movement that felt impactful had no
impact on the sound''; ``The thrust are not well detected''; ``Add \emph{thrust} detection
support or fix the existing''). None of the nine shipping presets currently derives a
dedicated signal from a stab or strike beyond the generic transient described in
\S\ref{ssec:qualities}, so this is a concrete, convergent request for a motion quality the
mapping vocabulary does not yet expose. A second, smaller cluster of feedback concerned the
node-graph editor itself rather than any preset: one participant who otherwise rated the
instrument highly asked for the wiring interface to be made easier, ``maybe some kind of
tutorial'', echoing the same complexity the graph exposes to a performer who only wants to
play, already named as a limitation in \S\ref{sec:discussion}. Reported frustration was
otherwise mostly framed as ordinary friction rather than a reason to stop - ``no, really
easy and when a bit hard it's just a learning experience!'', ``did not make me want to stop
but had to adjust'' - with one exception noting the instrument felt enjoyable to play but
did not, on its own, motivate further practice.

\section{Discussion}
\label{sec:discussion}

Everything described above is grounded in the system as it runs today, exercised
continuously through the first author's own development and rehearsal, and now also in
the pilot session reported in \S\ref{sec:evaluation}: ten first-time players found the
instrument comfortable and absorbing enough to lose themselves in, while converging
independently on the same gap - thrust and strike detection - as the mapping
vocabulary's clearest missing piece. Ten participants is a pilot, not a validated
usability study, and the claims above should be read accordingly.

The instrument also carries limitations worth naming plainly: Wi-Fi pairing is still a
manual, reflash-to-change affair rather than a runtime setting, even after the dropout
handling itself was tightened (\S\ref{sec:system}); yaw drift is bounded to sessions of
tens of minutes by assumption rather than measurement; the single inertial sensor gives
REMORA no sense of a second performer, so it remains a solo instrument for now; and the
node-graph editor, while it is what makes the preset catalog reproducible and extensible
at all, exposes that same complexity to a performer who only wants to pick a preset and
play, with no simplified performance-only view that hides the graph until it is asked
for.

One extension is next on the list regardless of the evaluation's findings above:
replacing the compiled-in Wi-Fi hotspot join with an ESP-NOW peer-to-peer link between
the staff's microcontroller and a second one tethered to the host, which would drop the
SSID, password, and destination IP address currently baked into firmware in favour of
pairing by MAC address, at the cost of one extra piece of hardware in the signal chain.

\section{Conclusion}
\label{sec:conclusion}

REMORA reads a martial artist's own staff-handling vocabulary - spins, tilts, strikes -
directly off a b\^o and turns it into sound, without baking any single gesture-to-sound
behaviour into compiled code: every mapping is instead a small, rewireable patch built
from the same handful of source, math, and sink nodes, stretching from the one-line
\preset{Simple} mapping to the self-varying \preset{Azimut Kinetic} (\S\ref{sec:mapping}).
Nine presets built from that vocabulary currently ship, pruned down from fifteen once
overlapping mappings became apparent (\S\ref{sec:presets}). What this paper has
established is that the instrument works end to end, from a self-calibrating sensor
unit through to three distinct synthesis voices (\S\ref{sec:system}), and that it does
so in hands other than its designer's: a ten-participant pilot (\S\ref{sec:evaluation})
found it comfortable and absorbing to play regardless of prior martial-arts or music
background, while converging on strike detection as the first thing to fix. Confirming
that finding at a larger scale, together with the ESP-NOW rework in
\S\ref{sec:discussion}, is what's next.

\section{Acknowledgment}
\label{sec:ack}

This work was carried out during the first author's internship at CREATE, Aalborg
University, Denmark. Firmware, plugin source, enclosure files, and the current preset
catalog (plus the retired mappings kept as reference graphs, \S\ref{sec:presets}) are
available at \url{https://github.com/TimotheeDvt/REMORA}.

\balance
\bibliographystyle{avs}
\bibliography{references}

\end{sloppy}
\end{document}

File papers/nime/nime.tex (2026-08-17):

\documentclass[sigconf,nonacm]{acmart}

\usepackage{booktabs}
\usepackage{tikz}
\usetikzlibrary{arrows.meta, positioning, fit, shadows, calc}

\newcommand{\coderef}[1]{{\small [#1]}}
\newcommand{\preset}[1]{\textit{#1}}

\copyrightyear{2027}
\acmYear{2027}
\setcopyright{cc}
\setcctype{by}
\acmConference[NIME '27]{International Conference on New Interfaces for Musical Expression}{2027}{}

\title{\texorpdfstring{\vspace*{-50pt}\\[4pt]}{}REMORA: Real-time Expressive Motion to Output Routing Audio}

\author{Timothée Dravet}
\affiliation{%
  \institution{Polytech Marseille, Aix-Marseille Université}
  \country{France}
}
\email{timothee.dravet@etu.univ-amu.fr}

\author{Daniel Overholt}
\affiliation{%
  \institution{CREATE, Aalborg University}
  \country{Denmark}
}
\email{dano@create.aau.dk}

\renewcommand{\shorttitle}{}
\renewcommand{\shortauthors}{}

\begin{document}

\begin{abstract}
REMORA turns a martial arts staff (b\^o) into a musical instrument: spins, tilts, and strikes become
sound in real time. A wireless sensor unit on the staff tracks its motion and sends it to a
companion audio plugin, which we built around a simple idea - instead of hard-wiring one fixed
gesture-to-sound behaviour, the mapping itself is a small patch of connected building blocks that
the performer can see and rewire live, on a visual canvas inside the plugin, much like a modular
synthesiser. We show that this same small set of building blocks is enough to reproduce, as editable
patches, everything from simple tilt-controlled pitch to compound movement-quality mappings inspired
by Laban Movement Analysis. This paper describes the instrument's hardware, its self-calibration
method, the mathematics behind turning raw orientation into musical control, and the live patching
interface itself. We situate it against prior staff-shaped, baton, and visual-patching instruments.
Grounded in implementation-level evidence, together with a protocol for the performer evaluation
still to be run, we reflect on what it means to make an instrument's gestural vocabulary an
explicit, editable part of the instrument.
\end{abstract}

\begin{CCSXML}
<ccs2012>
<concept>
<concept_id>10010405.10010496</concept_id>
<concept_desc>Applied computing~Sound and music computing</concept_desc>
<concept_significance>500</concept_significance>
</concept>
<concept>
<concept_id>10011007.10011006.10011050.10011058</concept_id>
<concept_desc>Software and its engineering~Visual languages</concept_desc>
<concept_significance>300</concept_significance>
</concept>
</ccs2012>
\end{CCSXML}
\ccsdesc[500]{Applied computing~Sound and music computing}
\ccsdesc[300]{Software and its engineering~Visual languages}
\makeatletter
\renewcommand\@concepts{%
  \textbullet\ \textbf{Applied computing} \textrightarrow\ \textbf{Sound and music computing};\\
  \textbullet\ \textbf{Software and its engineering} \textrightarrow\ \textit{Visual languages}.}
\makeatother

\keywords{digital musical instrument, gestural control, inertial sensing, Laban Movement Analysis,
OSC, staff instrument}

\maketitle

\section{Introduction}

\subsection{Motivation and Background}
REMORA grew out of the first author's parallel practice in martial arts and music, and a frustration
shared by many hand-built digital musical instruments: once a gesture vocabulary is designed and
coded, changing it means rebuilding the instrument rather than performing with it. That friction is
the paper's real starting point - not which single mapping best suits a staff, but whether a staff
instrument's gestural vocabulary could instead be something the performer authors and revises live,
the way a modular-synthesis patch is built and rebuilt on a rack.

The b\^o staff itself is a form factor that New Interfaces for Musical Expression (NIME) instruments
have rarely explored: a full-body, swung, two-handed controller with its own rotational inertia
and reach, distinct from the small handheld or body-mounted objects most inertial-sensor Digital
Musical Instruments (DMIs) use. Pairing that distinctive controller form with a
mapping layer that can be reshaped at performance time, rather than fixed at design time, is the
combination this paper investigates.

\subsection{Objectives of the Study}
This article supports four claims, each grounded in the system as it currently operates:
\begin{enumerate}
\item \label{claim:dag} A small dataflow language - source, math, and sink node primitives - is embedded directly in
the audio plugin and evaluated once per audio block as a directed acyclic graph (DAG); the performer
rewires it live, without recompiling any code.
\item \label{claim:presets} That same handful of primitives is expressive enough to reproduce eleven previously hand-coded
mapping strategies as ordinary presets: the mapping design space explored by hand over the course of
the project turns out to be spanned by a fairly compact algebra of building blocks.
\item \label{claim:facing} A magnetometer-free, world-frame heading estimate (``facing'') is derived purely from the
calibrated orientation stream, eluding the magnetic interference a stage rig would otherwise cause -
a claim we bound to session lengths on the order of tens of minutes, since uncorrected gyroscopic
yaw drift is expected to accumulate over longer, uninterrupted play (\S\ref{sec:limitations}).
\item \label{claim:calibration} A mount-agnostic calibration transform lets the same instrument logic run correctly regardless
of where the sensor is physically mounted on the staff.
\end{enumerate}

\subsection{Scope and Applications}
The instrument's intended context follows directly from its origin: a solo performer with some
staff or martial-arts background, playing a set built from one or more presets rather than a fixed,
single-piece score. The preset catalog (Table~\ref{tab:preset-nodes}) is deliberately graded rather than uniform - \preset{Simple}
asks only for basic tilt and roll, while the Laban-driven \preset{Martial} and \preset{Azimut} presets reward
staff-handling vocabulary the performer already has from bo practice - so the same instrument can
serve a newcomer exploring gesture-to-sound relationships and a martial artist bringing an existing
physical vocabulary onto a stage. Because the mapping itself is authored in the same visual
language a modular-synthesis performer would recognise, we also see REMORA as being of interest to
patch-based electronic musicians looking for a full-body controller to wire into an existing
practice, not only to staff practitioners looking for a way into live electronics. We do not,
however, claim REMORA is suited to ensemble or accompanied performance in its current form: the
single-IMU, single-staff design in \S\ref{sec:limitations} means the instrument has no notion of a
second performer's motion, and no mapping in the current catalog was designed with an ensemble
context in mind.

\newpage
\section{Related Work}

\subsection{Staff, Rod, and Baton DMIs}
Rod-, staff-, and baton-shaped controllers form a recurring family of DMIs, spanning handheld
sensor-augmented rods, conducting tools, and swung objects.

\textit{T-Stick}~\cite{malloch2007tstick} - a family of rod-shaped controllers sensing finger
position and pressure along the shaft via capacitive touch, together with accelerometer-derived
shake and tap gestures. The sensing is paired with an external, reconfigurable mapping layer built
around the digital-orchestra/libmapper tools, so the gesture vocabulary can be revised without
changing the hardware.

\textit{Digital Baton}~\cite{marrin1997digitalbaton} - Marrin and Paradiso's controller, combining
accelerometers, infrared position tracking, and a pressure-sensitive tip to capture continuous
conducting gesture rather than discrete note events.

\textit{Conductor's Jacket}~\cite{marrin1998conductorsjacket} - a wearable, full-body
electromyography (EMG) and motion rig extending the same conducting-gesture goal to the whole body,
recording muscle tension and movement alongside the baton's hand-level detail.

\textit{Musical Poi (mPoi)}~\cite{nam2013mpoi} - Nam's sensor-augmented poi, generating sound from
swing motion; a compact, single-mapping instrument that established spun/swung objects as a
recognised, if uncommon, DMI form.

\subsection{Inertial Sensing and Visual Patching in NIME}
Visual dataflow patching and Laban-derived movement analysis are two long-running, separate
threads in NIME and related work: one concerned with how a mapping is authored and rewired, the
other with what expressive qualities a mapping can draw on.

\textit{Max}~\cite{puckette1988patcher} - originated as Puckette's Patcher and has been maintained
and extended commercially for over three decades, a history Puckette himself traces in
``Max at Seventeen''~\cite{puckette2002maxatseventeen}. It established the boxes-and-patch-cords
model of unit generators wired together and rewired live that much of visual audio programming
still follows.

\textit{Pure Data}~\cite{puckette1996puredata} - Max's open-source sibling, built around the same
patching model and widely used in NIME instrument-building for its extensibility and free
licensing.

\textit{VCV Rack}~\cite{belt2017vcvrack} - a community-maintained open-source descendant of the same
patching idea applied to virtual modular synthesis, letting performers wire together emulated
Eurorack-style modules on screen.

\textit{EyesWeb}~\cite{camurri2000eyesweb} - Camurri et al.'s system for extracting expressive
movement qualities from full-body motion in real time, grounded in Laban's Effort theory and built
for interactive dance and music applications.

\textit{DAMPER}~\cite{bennett2007damper} - Bennett et al.'s force-feedback interface platform, built
on Laban's four Effort factors as the direct design basis for its haptic response.

Ward et al.~\cite{ward2008thereminists} - use Laban Effort - Flow and the Recuperation phase of
Effort phrasing in particular - as an analytic lens on theremin performers' movement, to inform how
future instruments might be designed around it.

Schacher~\cite{schacher2010motiontogesture} - argues for Laban-derived motion/effort elements as a
systematic basis for gesture-to-sound mapping in interactive dance, rather than an ad hoc or
purely descriptive analysis tool.

\subsection{Mapping Strategies}
Beyond specific instruments, a body of work addresses gesture-to-sound mapping as a design problem
in its own right, independent of any single controller's hardware.

Hunt and Wanderley~\cite{hunt2002mapping} - categorise gesture-to-synthesis mappings by complexity -
one-to-one, one-to-many, many-to-one - and argue that richer, many-to-many mappings are what make an
interface feel like an instrument rather than a remote control.

\textit{Wekinator}~\cite{fiebrink2010wekinator} - Fiebrink and Cook's system for authoring a
gesture-to-sound relationship via interactive machine learning: a performer or designer supplies
example gestures and desired outputs, and regression learns the mapping, without either party
writing or wiring an explicit mapping function.

\section{Design and System Architecture}

\subsection{Initial Design Requirements}
Five requirements shaped the design from the outset, chosen to keep the instrument performable:
\begin{itemize}
    \item \textbf{Full-body, swingable staff form factor.} Not a handheld controller: the instrument
must support the reach, weight, and two-handed grip of an actual b\^o - roughly 1.5\,m long - not a
miniaturised stand-in for one.
    \item \textbf{Wireless sensing during performance.} A cable is acceptable only for charging
between sets; nothing should tether the performer to a fixed point on stage.
    \item \textbf{Live-editable mapping.} Switching or rewiring the mapping graph must not interrupt
audio output, so a change can be made mid-rehearsal without stopping the sound.
    \item \textbf{Mount-agnostic calibration.} Instrument behaviour must not depend on precisely
where the sensor is glued to the staff, since exact placement varies from build to build and cannot
be guaranteed reproducible by hand.
    \item \textbf{Low end-to-end latency.} The staff has to feel driven by the performer's motion,
not lagging behind it, which bounds how much time sensing, transport, and synthesis are together
allowed to take.
\end{itemize}

\subsection{Architecture Overview}
REMORA's architecture has two parts: firmware handles sensing and transport,
and the plugin handles everything downstream of the incoming Open
Sound Control (OSC) stream, from calibration through to the audio it produces.
Figure~\ref{fig:architecture} lays out that split directly,
left to right: IMU sampling and OSC transmission on the staff, feeding the plugin's own
reception-to-synthesis pipeline on the host.

\begin{center}
\begin{tikzpicture}[
  box/.style={draw, rounded corners, align=center, text width=2.1cm, minimum height=0.55cm,
    font=\small\bfseries, inner sep=2pt},
  sub/.style={draw, align=center, text width=1.9cm, minimum height=0.45cm, font=\scriptsize,
    inner sep=1.5pt},
  arr/.style={-{Latex[length=1.5mm]}}
]
\node[box] (staff) {Firmware};
\node[sub, below=0.6mm of staff] (collect) {IMU sampling};
\node[sub, below=0.8mm of collect] (send) {OSC transmission};
\draw[arr] (collect) -- (send);

\node[box, right=26mm of staff] (host) {REMORA plugin};
\draw[arr] (staff) -- (host)
  node[midway, above, font=\scriptsize, align=center] {Wi-Fi / UDP / OSC};

\node[sub, below=0.6mm of host, xshift=-1.03cm] (recv) {OSC reception};
\node[sub, right=1.5mm of recv] (calib) {Calibration};
\draw[arr] (recv) -- (calib);
\node[sub, below=0.8mm of calib] (graph) {Graph evaluation};
\node[sub, below=0.8mm of recv] (synth) {Synthesis};
\draw[arr] (calib) -- (graph);
\draw[arr] (graph) -- (synth);
\end{tikzpicture}

\small
\refstepcounter{figure}\label{fig:architecture}
\textbf{Figure \thefigure: REMORA's signal flow}, from IMU sampling on the staff to synthesis on the host.
\end{center}

\newpage
\section{Implementation}

\subsection{The Build}
The sensor unit sits in a small OpenSCAD-parametrised enclosure, sized to the b\^o's diameter.
Because calibration is mount-agnostic, it can be placed anywhere along
the staff - in practice usually near one extremity, out of the performer's grip - and is secured
with zip ties rather than adhesive or drilling, so it can be repositioned or removed freely.
\begin{center}
  

  \small
  \refstepcounter{figure}\label{fig:enclosure}
  \textbf{Figure \thefigure: The parametric OpenSCAD enclosure}, sized to the staff diameter and secured with
  zip ties.
\end{center}

\subsection{Hardware}
Inside the enclosure, a SparkFun ESP32-S2 Thing Plus reads a 9-degrees-of-freedom (9-DOF) MPU-9250
IMU over the Inter-Integrated Circuit (I2C) bus at 100~Hz and packs orientation, acceleration, and
gyroscope readings into an OSC packet sent over the UDP on port 8000. The
firmware joins the host
computer's own Wi-Fi hotspot directly rather than a dedicated access point, which keeps setup to a
single pairing step at the cost of the range and interference sensitivity Discussion returns to
(\S\ref{sec:limitations}).
\begin{center}
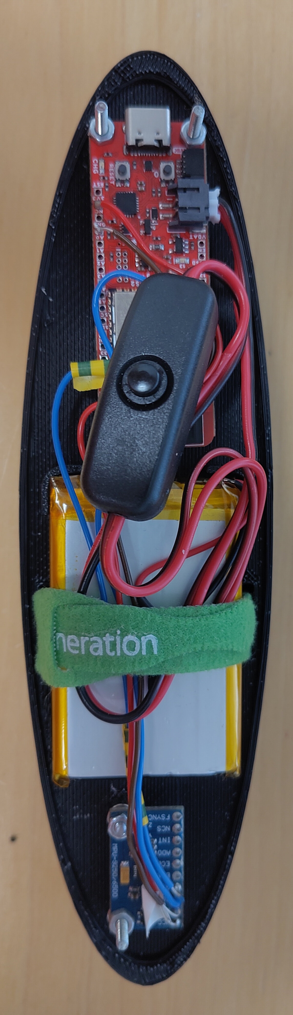
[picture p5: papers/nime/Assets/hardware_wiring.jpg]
  

  \small
  \refstepcounter{figure}\label{fig:hardware}
  \textbf{Figure \thefigure: Component arrangement inside the enclosure} - ESP32-S2, MPU-9250 IMU, and LiPo
  battery, wired as described in Hardware.
\end{center}

\subsection{Software: Calibration and Motion Mathematics}
\textit{Every equation below comes straight from the running code (optimized in the implementation),
each tagged with the function it lives in.}

\subsubsection*{Orientation and Calibration}

\textbf{Rotation.} Orientation is tracked as a unit quaternion (no gimbal lock); rotating $v$ by $q$
gives $v' = q\,v\,q^{-1}$, with $q^{-1}$ the conjugate. Euler angles are derived only once, at the
end, for the handful of mappings that still need them.
\begin{flushright}
\coderef{\texttt{MathHelpers::rotate}} \coderef{\texttt{conjugate}} \\
\coderef{\texttt{rotateVectorByQuaternion}}
\coderef{\texttt{toEuler}} \coderef{\texttt{multiply}}
\end{flushright}

\textbf{Calibration, stage 1 - which axis is ``forward''.} The sensor can be glued onto the staff at
any orientation, so each candidate axis $L \in \{\pm X, \pm Y, \pm Z\}$ is scored against three
reference poses $A,B,C$ (quaternions $q_A,q_B,q_C$, chosen so forward varies substantially between
them while up/right do not):
\[
v_P = \widehat{\mathrm{rotate}(L, q_P)}\,,\qquad e(L) = |v_A{\cdot}v_B| + |v_B{\cdot}v_C| +
|v_C{\cdot}v_A|
\]
A low $e(L)$ (near-orthogonal $v_A,v_B,v_C$) marks the genuine forward axis; restricted to
right-handed candidates,
\[
L^\ast = \operatorname*{arg\,min}_{L\,:\,(v_A \times v_B)\cdot v_C < 0} e(L)
\]
gives the alignment quaternion $q_{\text{align}}$.
\begin{flushright}
\coderef{\texttt{computeAlignQuat}}
\end{flushright}

\textbf{Stage 1 failure modes.} \texttt{computeAlignQuat} reports failure when the three poses are
too close together or nearly coplanar to fix a physical axis with confidence, and the User Interface
(UI) surfaces this
as a "Calibration failed, try again" prompt.

\textbf{Calibration, stage 2 - fixing the twist.} The sensor could still be rotated around
$L^\ast$. The measured forward/up/right triad and the ideal instrument-frame triad are each
orthonormalized via Gram-Schmidt into $U$ and $W$; the aligning rotation is the orthogonal-Procrustes
closed form
\[
R = W U^{\top}\,,
\]
converted to a quaternion $q_{\text{corr}}$ via Shepperd's method.
\begin{flushright}
\coderef{\texttt{computeCorrection}}
\coderef{\texttt{MathHelpers::fromMatrix}}
\end{flushright}

\textbf{Runtime.} Every live reading becomes instrument space via
$q' = q_{\text{corr}}\,(q_{\text{raw}}\,q_{\text{align}})$ - independent of where the sensor sits on
the staff.
\begin{flushright}
\coderef{\texttt{REMORAProcessor::getCalibratedQuat}}
\end{flushright}

\subsubsection*{Motion Feature Extraction}

\textit{Everything below runs once per received packet, inside the shared analyzer that every
mapping graph reads from - so no individual mapping repeats this work.} The smoothing rates,
thresholds, and envelope times named throughout this subsection were tuned by ear against the
physical instrument during iterative testing, not derived analytically or fit to recorded data; see
Discussion for the resulting lack of a perceptual evaluation of these choices.
\begin{flushright}
\coderef{\texttt{StaffMotionAnalyzer::computeFrame}}
\end{flushright}

\begin{table}[htbp]
\centering
\small
\caption{Per-packet motion features.}
\label{tab:motion-features}
\begin{tabular}{@{}p{0.32\linewidth}p{0.58\linewidth}@{}}
\toprule
Feature & Purpose \\
\midrule
Timestep $\Delta t$ & reject implausible packet gaps \\
Tip vector / rotation axis & derive tip velocity \& spin axis \\
Gravity / dynamic accel. & separate gravity from motion \\
Laban Weight & movement forcefulness \\
Laban Time & suddenness of rotation-speed change \\
Laban Space & spin-axis consistency (focus) \\
Laban Flow & bound vs.\ free movement \\
Spin classification & vertical/horizontal spin \& direction \\
Facing & east-west vs.\ north-south heading \\
Continuous spin count & count full turns per spin \\
Axial thrust & detect stab/strike along staff axis \\
\bottomrule
\end{tabular}
\end{table}

\textbf{Timestep.} $\Delta t$ is the time between two packets, clamped to a $0.1$-$200\,\text{ms}$
valid range so a dropped or duplicated packet can't send the integrators below flying.
\begin{flushright}
\coderef{\texttt{calculateDeltaTime}}
\end{flushright}

\textbf{Tip vector and rotation axis.} The tip direction\\ $p_n = \mathrm{rotate}((1,0,0), q_n)$ is
buffered over the last three samples to derive tip velocity and, from that, the axis the staff is
currently spinning around.
\begin{flushright}
\coderef{\texttt{updateTipPositionHistory}}
\coderef{\texttt{calculateRotationAxisAtMidpoint}}
\end{flushright}

\textbf{Gravity and dynamic acceleration.} The accelerometer always mixes gravity in with whatever
motion the performer is making. To separate the two, REMORA keeps a running estimate of which way
``down'' currently is, by smoothing the inverse-rotated world $+Z$ axis:
\[
g_n = \mathrm{onePole}\big(g_{n-1},\ \mathrm{rotate}(+Z,\, q_n^{-1}),\ \alpha{=}0.10\big)
\]
Subtracting this gravity estimate from the raw reading leaves just the motion: $a_{\text{dyn}} =
a_{\text{raw}} - g$.
\begin{flushright}
\coderef{\texttt{updateGravityVector}}
\coderef{\texttt{calculateDynamicAcceleration}}
\end{flushright}

\textbf{Laban features.} All four Laban Effort qualities reduce to the same shared one-pole
smoother,
\[
y_n = y_{n-1} + \alpha\,(x_n - y_{n-1})\,,\qquad \alpha \in (0,1]\,,
\]
applied to a derivative of either dynamic acceleration or gyroscope magnitude: Weight integrates
dynamic acceleration into a leaky velocity estimate (its magnitude, fast-attack/slow-release
enveloped) to capture forcefulness; Time is the clamped-positive rate of change of \emph{raw}
gyroscope magnitude, capturing suddenness; Space is the smoothed absolute dot product between
consecutive rotation-axis directions, capturing how consistently the staff spins around the same
axis versus wandering; Flow is the smoothed, clamped jerk of dynamic-acceleration magnitude, split
into \texttt{flow\_bound} (controlled) and $1-\texttt{flow\_bound}$ (free).
\begin{flushright}
\coderef{\texttt{MathHelpers::applyOnePoleFilter}}
\coderef{\texttt{integrateVelocityForLabanWeight}}
\coderef{\texttt{updateLabanWeight}}
\coderef{\texttt{updateLabanTime}}
\coderef{\texttt{updateLabanSpace}}
\coderef{\texttt{updateLabanFlow}}
\end{flushright}

\textbf{Spin classification.} Is the staff spinning like a baton (vertical) or more like a fan blade
(horizontal)? Let $(\mathrm{axis}_x,\mathrm{axis}_y,\mathrm{axis}_z)$ be the $\alpha{=}0.35$
one-pole-smoothed rotation axis from above. The spin is classified vertical when
\[
\sqrt{\mathrm{axis}_x^2 + \mathrm{axis}_y^2}\ \gtrless\ |\mathrm{axis}_z|\,,
\]
i.e.\ when the horizontal-plane component outweighs the $z$ component. Spin direction
(clockwise/counter-clockwise, CW/CCW) then
comes either from the sign of the dominant in-plane axis component, or - in the Martial mappings -
from the sign of that axis's dot product against a reference heading latched once, the first time a
qualifying vertical spin happens after the mapping loads.
\begin{flushright}
\coderef{\texttt{updateSpinClassificationByAbsoluteComponent}}
\coderef{\texttt{updateSpinClassificationByReferenceAzimuth}}
\end{flushright}

\textbf{Facing.} Rather than compute a compass heading - which would need a magnetometer, and stages
are full of magnetic interference - REMORA asks a simpler question: is the staff pointing more
east-west or more north-south? Let $(\mathrm{dir}_x,\mathrm{dir}_y)$ be the horizontal-plane
components of whichever direction is currently relevant - the rotation axis during vertical spins,
the tip direction during horizontal ones. Facing is then just a hysteresis comparison,
\[
|\mathrm{dir}_x| \ \gtrless\ 1.15\cdot|\mathrm{dir}_y|\,,
\]
where the $1.15$ factor gives asymmetric switch points ($\approx\!48^\circ/42^\circ$) so the
classification doesn't flicker right at the boundary.
\begin{flushright}
\coderef{\texttt{updateFacingClassification}}
\end{flushright}

\textbf{Continuous spin count.} Full turns in the current spin, from $\lVert\omega\rVert\cdot\Delta t$
accumulated to $360^\circ$ per lap; resets whenever the spin classification changes.
\begin{flushright}
\coderef{\texttt{accumulateContinuousSpins}}
\end{flushright}

\textbf{Axial thrust detection.} Flags a stab/strike when the jerk of the tip-projected dynamic
acceleration crosses zero as its magnitude passes $1.5\text{g}$, gated against fast spins
($\lVert\omega\rVert < 90^\circ/\text{s}$) and cooled down between hits.
\begin{flushright}
\coderef{\texttt{detectAxialThrustPeaks}}
\end{flushright}

\textbf{Sensitivity of tuned constants.} Each constant above biases the instrument in a specific
direction. The gravity smoother's $\alpha{=}0.10$ trades under-reporting fast
motion (too high) against a lagging estimate that produces a spurious motion blip when the staff is
set down (too low). The spin-axis smoother's $\alpha{=}0.35$ plays the same role for Laban Space:
higher reads axis noise as ``inconsistent'' too readily, lower reads a genuinely wandering spin as
falsely focused. The facing hysteresis factor ($1.15$) sets the $\approx\!48^\circ/42^\circ$
dead-band; $1.0$ reintroduces boundary flicker, while a much larger factor makes facing changes
sluggish to register. The thrust detector's $1.5\text{g}$ threshold and $90^\circ/\text{s}$ gate trade
false triggers during forceful spins (too low) against missed soft stabs (too high).

\subsection{Software: Mapping Architecture}
\textit{\texttt{NodeGraph}/\texttt{NodeTypeRegistry}: four node categories - Source (IMU,\\
Laban features), Math (arithmetic, shaping, dynamics, lookup tables), Sink (synth-engine
parameters, one resizable ``mega-node'' per engine exposing every one of that engine's parameters
as its own typed input port, \S\ref{sec:synthesis}),
and Display (resizable, performer-facing live monitors, \S\ref{sec:live-patching}) - each a
small typed function registered once. A graph is nodes plus typed wiring, serialised to/from the
Extensible Markup Language (XML) as
a preset; \texttt{GraphMappingStrategy} makes the graph the only mapping path the synth talks to,
with no separate hand-written path.}

\subsubsection*{Graph Evaluation and Primitive Library}

\textbf{DAG evaluation.} A patch is a directed graph of typed nodes; \texttt{NodeGraph::connect}
provisionally adds an edge and recomputes a topological order with Kahn's algorithm via
\texttt{NodeGraph::recomputeTopoOrder}, reverting the edge if the graph fails to fully drain (a
closed cycle). Each audio block, \texttt{NodeGraph::evaluate} walks the cached order once, and every
node computes
\[
y_i = f_{\text{type}(n_i)}\big(x_{i,1},\dots,x_{i,m}\,;\,\theta_i\big)
\]
where $n_i$ is the $i$-th node in topological order, $\text{type}(n_i)$ its registered node-type
function, $x_{i,1},\dots,x_{i,m}$ its wired inputs, $\theta_i$ its parameters, and $y_i$ its output(s)
- so the whole patch is one composed function of the sensor frame, evaluated once per block with no
re-sorting on the audio thread.

\textbf{Primitive vocabulary.} Every node type is one small pure function (or, for stateful ones, a
function plus a scratch struct): arithmetic (add/subtract/multiply/divide/abs/max/min/equals),
shaping (mapRange, clamp, threshold, crossfade, quantizeSteps, sine, atan2, semitonesToHz), lookup
tables (a general 1-D table and the 3-boolean-selector table used by the \preset{Azimut} root table below),
and stateful dynamics (one-pole smoother, leaky integrator, retrigger envelope, hysteresis step,
derivative, latched smoother).
\begin{flushright}
\coderef{\texttt{Graph::buildAllNodes}}
\end{flushright}

\subsection{Software: Named Mappings as Graph Presets}
\label{sec:named-mappings}
Table~\ref{tab:preset-nodes} shows the generalisation claim directly: each of the eleven mappings - \preset{Simple}, \preset{Lead+Drone},
\preset{Spin Filter}, \preset{Bowed Chord}, the \preset{Azimut} family (facing-based root table, spin-count filter sweep, axial
thrust transients), \preset{Martial Effort}/\preset{Martial Momentum}, \preset{Spin Voices}, and \preset{Speed Gate} - is built once via \texttt{GraphBuilder}
and is structurally just a particular wiring of the same node catalog. Counts are read directly off
the constructed graphs (\texttt{NodeGraph::nodes()}).

Four further presets - \preset{Wind Noise}, \preset{Azimut Kinetic}, \preset{Spin Voices (Scale)}, and
\preset{Vocal Tract} - sit outside that generalisation claim: unlike the eleven above, none of them
was ever a separate hand-coded C++ mapping class first: they were authored directly as graph
patches, so they demonstrate the catalog's expressiveness going forward rather than its ability to
reproduce a prior hand-built design. \preset{Vocal Tract} is also the one preset that drives the
vocal-tract engine instead of the additive one (\S\ref{sec:synthesis}). Counting these, the catalog
currently ships fifteen presets in total.
% TODO before submission: regenerate Table~\ref{tab:preset-nodes} node counts from a live build -
% the Sink column for every existing row is stale (per-parameter sink nodes were consolidated into
% per-engine mega-nodes, changing the Sink/Nodes totals), and the four new rows below need real
% counts in place of the "tbd" placeholders.
\begin{table}[htbp]
\centering
\small
\caption{Node composition of each named-mapping preset.}
\label{tab:preset-nodes}
\begin{tabular}{@{}lrrrr@{}}
\toprule
Preset & Nodes & Source & Math & Sink \\
\midrule
Simple         & 7  & 2 & 3   & 2 \\
Wind Noise     & \textit{tbd} & \textit{tbd} & \textit{tbd} & \textit{tbd} \\
Bowed Chord    & 110 & 25 & 54  & 31 \\
Lead+Drone     & 96 & 23 & 45  & 28 \\
Spin Filter    & 105 & 30 & 54  & 21 \\
Martial Effort   & 207 & 46 & 130 & 31 \\
Martial Momentum & 109 & 32 & 48  & 29 \\
Azimut         & 113 & 32 & 52  & 29 \\
Azimut+        & 113 & 32 & 52  & 29 \\
Azimut Reverb  & 123 & 33 & 58  & 32 \\
Azimut Kinetic & \textit{tbd} & \textit{tbd} & \textit{tbd} & \textit{tbd} \\
Speed Gate       & 181 & 87 & 95 & 29 \\
Spin Voices      & 99 & 34 & 36  & 29 \\
Spin Voices (Scale) & \textit{tbd} & \textit{tbd} & \textit{tbd} & \textit{tbd} \\
Vocal Tract    & \textit{tbd} & \textit{tbd} & \textit{tbd} & \textit{tbd} \\
\bottomrule
\end{tabular}
\end{table}
% TODO before submission: the "63 of 79" figures below are stale on both ends - the registered
% node-type catalog is smaller now (mega-node sink consolidation removed ~17 per-parameter sink
% types), and the "63 used" count needs recomputing against whatever the new total is. Recompute
% both from a live build rather than editing these numbers by hand.
Across all eleven presets, only 63 of the catalog's 79 registered node types are ever
instantiated - 42 of those source/math primitives, the rest sink writers. A full development cycle
of hand-built mapping design, spanning a solo tilt-controlled mapping through the fully Laban-driven
\preset{Martial} and \preset{Speed Gate} patches, lands inside less than two-thirds of an already small catalog; no preset
needed a node type invented specifically for it. That result should be read carefully, though: the
catalog itself was not fixed in advance and then tested against eleven independent designs - it grew
alongside the eleven mappings, several of which were the reason a given primitive was added in the
first place. What Table~\ref{tab:preset-nodes} demonstrates is internal consistency (the resulting catalog is compact
enough to re-express every mapping it was abstracted from as a preset, rather than needing a
bespoke escape hatch per mapping), not that the catalog would prove sufficient for a gesture
vocabulary designed independently of it. Whether a mapping designer outside this project can build
a genuinely new movement-quality mapping from the existing 63 node types without hitting a missing
primitive is an open question the current evidence does not settle.
\begin{flushright}
\coderef{\texttt{NodeGraph::nodes}} \coderef{\texttt{Graph::Presets::AllPresets}}
\end{flushright}

\subsubsection*{Azimut-Specific Transformations}
\textit{Shared by every Azimut-family preset.}

\textbf{Root-note table.} The spin-plane/direction/facing root-note table above is not an if/else
chain - it is literally an 8-entry lookup table (LUT) indexed by three booleans (\texttt{isVertical},
\texttt{isCCW}, \texttt{isFacingEast}) through the graph's generic 3-selector LUT node.

\textbf{Root morph.} The target semitone value is chased by a variable-rate one-pole filter whose
rate is
\[
\text{rate} = \max\Big(\mathrm{clamp}\big(\tfrac{\lVert\omega\rVert}{2000},\,0.005,\,0.2\big)\,,\ \
0.5\cdot\text{onsetEnv}\Big)
\]
where \texttt{onsetEnv} is a retrigger envelope (decay $0.90$) that fires the instant the staff
leaves rest - faster motion, or a fresh onset, morphs the root pitch in quicker.

\textbf{Filter sweep.} The spin count drives a phase modulator whose sine output is remapped onto
the filter's cutoff range and smoothed:
\begin{align*}
c_{\text{raw}} &=
\mathrm{mapRange}\big(\sin(1.5\cdot\text{spinCount})\,,\,[-1,1]\,,\,[400,20000]\text{Hz}\big) \\
\text{cutoff} &= \mathrm{onePole}\big(c_{\text{raw}}\,,\ \text{rate}{=}0.03\big)
\end{align*}
where $\text{spinCount}$ is the unsigned lap counter from Continuous Spin Count above,
$\mathrm{mapRange}$ linearly rescales its argument from the first interval to the second,
$c_{\text{raw}}$ the resulting unsmoothed cutoff target, and $\mathrm{onePole}$ the smoothing
primitive defined earlier.
\begin{flushright}
\coderef{\texttt{Graph::Presets::buildAzimutCore}}
\coderef{\texttt{buildSpinCountLpfHz}}
\end{flushright}

\subsection{Graphical Interface: Live Patching as Performance Practice}
\label{sec:live-patching}
The node-graph editor is the instrument's primary authoring surface, not a debug tool: a pannable,
zoomable canvas on which each node renders as a coloured card - green for Source,
yellow for Sink, purple for Display, neutral for Math - labelled with its category and inline,
live-editable parameter fields; typed input/output pins along each card's edges accept
click-and-drag connections rendered as cubic-B\'ezier wires, colour-highlighted while dragging and
hit-testable afterward for rewiring or deletion via context menu, which for an existing wire also
offers jumping the view straight to its source or destination node, briefly highlighted on arrival
so the jump is easy to follow in a large patch. New nodes are added from a categorised picker at any
canvas position, each entry annotated with a short description of its behaviour; a search bar
over the same picker jumps directly to a node type by name. An auto-layout pass ranks every node by
longest path from a source, pulls sink-only nodes as late as their wiring allows, threads
dummy nodes through any connection that spans more than one rank so a long wire does not cut across
intervening columns, and orders nodes within each resulting layer to reduce crossings - a layered
graph-drawing pass rather than a fixed column assignment, so a freshly loaded preset still untangles
left-to-right from source to sink but copes with the deeper, more irregular graphs later presets
produce. Hovering any node or pin surfaces its
current, live-updating value as a tooltip, and three dedicated Display node types - a numeric
readout, a level meter, and a scrolling scope - can be dropped inline on any wire and freely
resized, giving the performer a live, in-patch view of a signal without altering it (all three are
pure passthrough: the graph carries exactly the same value with or without one attached). Sink
mega-nodes (\S\ref{sec:synthesis}) are themselves width-resizable and label each port with its valid
range (e.g.\ \texttt{[20, 20000] LPF Cutoff}), so a wide parameter surface stays legible without a
separate details panel; at the opposite end of the size scale, constant-value nodes render as a
compact numeric box with no slider, so the canvas is not dominated by its simplest node type. A
dirty-state indicator tracks whether the active patch has diverged from its saved preset, with
one-click revert - so a performer can improvise a mapping change mid-rehearsal and either keep or
discard it, treating the mapping itself as something authored and iterated on at the same level as
the sound it produces. Each preset in the catalog also carries a short description,
surfaced in the preset selector, so a performer choosing between mappings mid-rehearsal is not
reading bare names.

\begin{center}
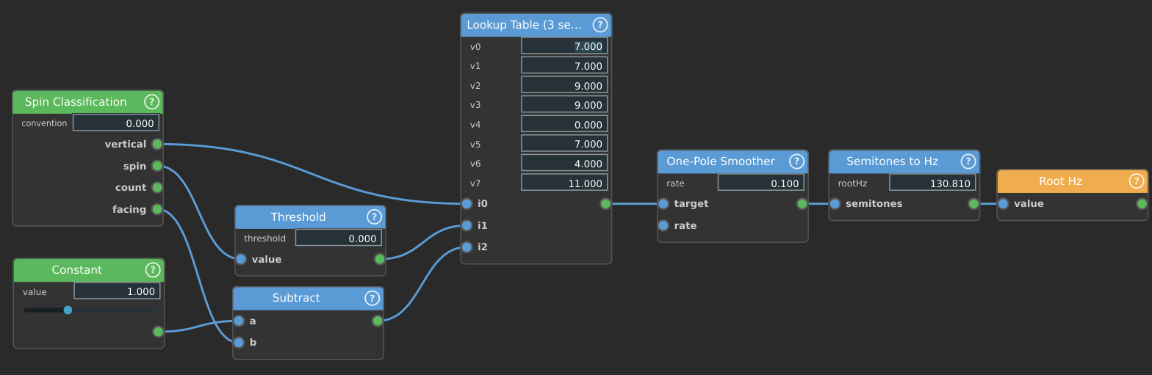
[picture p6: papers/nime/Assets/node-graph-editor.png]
  

  \small
  \refstepcounter{figure}\label{fig:editor}
  \textbf{Figure \thefigure: Schematic of the node-graph editor canvas} -
  coloured node cards (green Source, yellow Sink, purple Display, neutral Math) with typed pins,
  connected by Bézier-rendered wires.
\end{center}

\subsection{Software: Synthesis Engine}
\label{sec:synthesis}
Every mapping graph writes into a shared \texttt{SynthManager}, which owns a small, pluggable set
of synthesis engines behind one \texttt{ISynthEngine} interface (\texttt{prepare}/\texttt{render})
rather than a single hard-coded voice: an additive engine, a granular engine, and a physically
modelled vocal-tract engine. Each engine reads its own parameter struct - one field of the shared
\texttt{MappingOutput} the active graph writes every block, addressed through that engine's sink
mega-node (\S\ref{sec:named-mappings}) - and renders it into its own scratch buffer;
\texttt{SynthManager::processBlock} sums whichever engines the active preset actually wires in and
applies one shared master-gain/mute stage on top, keeping the engines themselves ignorant of which
preset or graph is driving them - which is what lets a graph be swapped or rewired live without
reinitialising audio. An engine a preset's graph leaves unwired is skipped entirely that block - no
parameter update, no render call - rather than rendered silently and discarded, so the additive-only
presets that make up most of the catalog never pay the granular or vocal-tract engines' cost.
\begin{flushright}
\coderef{\texttt{ISynthEngine}} \coderef{\texttt{SynthManager::processBlock}}
\end{flushright}

\subsubsection*{Additive Engine}
The original, still default, engine; every preset in Table~\ref{tab:preset-nodes} except
\preset{Vocal Tract} drives it.
\begin{flushright}
\coderef{\texttt{AdditiveSynthEngine::render}}
\coderef{\texttt{SynthVoice::tick}}
\end{flushright}

\textbf{Harmonic bank.} Each of the 4 voices sums 6 phase-accumulated sine partials at integer
multiples of a (vibrato- and chorus-modulated) fundamental, each with its own independently smoothed
target amplitude.

\textbf{Waveshaping.} A rational soft-clip saturator, applied per-voice when \texttt{driveAmt} $>0$:
\[
y = \frac{x\,(1+\text{driveAmt})}{1+\big|x\,(1+\text{driveAmt})\big|}
\]
where $x$ is the voice's summed harmonic-bank sample before shaping and \texttt{driveAmt} the
mapping-supplied drive amount.

\textbf{Resonator.} A short feedback comb (1800-sample delay, $0.35$ feedback, mixed $0.7$ dry /
$0.3$ wet) is layered onto every voice for a string-like coloration.

\textbf{Modulation.} Vibrato and tremolo are sinusoidal multipliers on pitch and gain respectively:
\[
f' = f\,\big(1+\text{depth}\cdot\sin\phi_v\big)
\qquad\qquad
g' = g\,\big(1-\text{depth}\cdot(0.5+0.5\sin\phi_t)\big)
\]
where $f, g$ are the fundamental frequency and master gain before modulation, $f', g'$ the modulated
values actually used, and $\phi_v, \phi_t$ the vibrato and tremolo Low-Frequency Oscillator (LFO)
phase accumulators (radians),
each advancing by its own rate every sample. A per-voice phase-offset sine (depth $0.003$, rate
$0.3$\,Hz) adds chorus detuning; chord changes cross-fade linearly between old and new semitone
offsets over $200$\,ms rather than jumping.

\textbf{Noise and filtering.} An xorshift32 pseudo-random number generator (PRNG) feeds a one-pole
lowpass (coefficient \texttt{noiseLpCoef}) before being mixed in at \texttt{noiseAmount}; the summed
stereo output passes through a JUCE state-variable Topology-Preserving Transform (TPT) lowpass, its
cutoff set directly each block from the \texttt{sink.additiveSynth} mega-node's \textit{LPF Cutoff}
port (only range-clamped, not ramped), and an optional Schroeder-style
\texttt{juce::dsp::Reverb} send whose wet level \emph{is} ramped through a per-sample
\texttt{SmoothedValue} to avoid zippering when the active mapping changes.

\textbf{Pitch/frequency conversion.}
\[
f = f_{\text{root}} \cdot 2^{\,\text{semitones}/12}
\]
where $f_{\text{root}}$ is the mapping's current root frequency in Hz and $\text{semitones}$ the
signed offset applied to it, giving the equal-tempered result $f$.
\begin{flushright}
\coderef{\texttt{MathHelpers::semitoneRatio}}
\coderef{\texttt{convertSemitonesToHertz}}
\end{flushright}

\subsubsection*{Granular Engine}
Has no audio input and bundles no sample assets: on \texttt{prepare} it synthesises its own
roughly 2-second internal source buffer (a slowly evolving harmonic bed layered with lightly
filtered noise), then continuously spawns and scans up to 64 overlapping grains across that buffer,
each with its own position, playback rate (a negative rate plays a grain backward), pan, and
amplitude envelope, driven every block by the mapping's granular parameter struct. Silent by
default, so a preset that never wires \texttt{sink.granularSynth} costs nothing beyond the skipped
check above. Currently used by \preset{Wind Noise}.
\begin{flushright}
\coderef{\texttt{GranularSynthEngine::buildSourceBuffer}}
\coderef{\texttt{GranularSynthEngine::spawnGrain}}
\end{flushright}

\subsubsection*{Vocal-Tract Engine}
The one engine not built for this project: an LF-model glottal source excites a digital-waveguide
vocal tract with oral and nasal branches, run at 2$\times$ oversampling, with two RBJ-cookbook
bandpass filters colouring raw white noise into breath and frication noise before it reaches the
model. The model itself is a C++ port (via \texttt{cutelabnyc/pink-trombone-cpp}, MIT-licensed) of
Neil Thapen's \textit{Pink Trombone}; REMORA's contribution at this layer is the driver around it -
control-rate parameter updates from the graph's \texttt{sink.pinkTromboneSynth} mega-node each
block - not the vocal-tract model itself. It is the one engine so far with a dedicated preset,
\preset{Vocal Tract} (\S\ref{sec:named-mappings}), rather than being an option within an
otherwise-additive mapping.
\begin{flushright}
\coderef{\texttt{PinkTromboneEngine::render}}
\end{flushright}

\subsection{Development Iterations}
The node-graph engine above did not arrive fully formed; it is the result of three iterations in
which generalisation followed rather than preceded hand-built mapping design. The first was
firmware reading the IMU and streaming OSC into a minimal receiver, driving a single hardcoded
tilt-to-pitch mapping, purely to prove the sensor-to-sound pipeline end to end. The second built
the eleven named mappings one at a time as their own C++ classes, each adding a new gesture
vocabulary (chords, Laban Effort, world-frame facing, transient detection) on top of the shared
\texttt{StaffMotionAnalyzer} - at which point a pattern became visible: every one of them was
really just arithmetic, shaping, and a handful of stateful primitives wired together in a fixed
pattern. The third iteration rebuilt the mapping layer as the small generic graph engine described
above, porting all eleven prior mappings over as presets rather than deleting them.

Since that third iteration, the same graph engine has absorbed two further kinds of growth without a
fourth architectural rewrite: a pluggable synthesis layer behind the sink nodes
(\S\ref{sec:synthesis}), adding granular and vocal-tract engines alongside the original additive
one, and four more presets - \preset{Wind Noise}, \preset{Azimut Kinetic}, \preset{Spin Voices
(Scale)}, \preset{Vocal Tract} - authored directly as graph patches with no hand-coded precursor to
port (\S\ref{sec:named-mappings}).

\section{Evaluation}
\label{sec:evaluation}
No performer evaluation has been run yet. This section separates what the current claims actually
rest on - implementation-level evidence internal to the system itself - from a protocol for the
performer session that would be needed to test the remaining, human-facing parts of those claims.
Table~\ref{tab:claims-evidence} summarises this split per claim; the subsections below explain each row.

\begin{table}[htbp]
\centering
\small
\caption{Claims, current evidence, and open questions.}
\label{tab:claims-evidence}
\begin{tabular}{@{}p{0.09\linewidth}p{0.44\linewidth}p{0.4\linewidth}@{}}
\toprule
Claim & Current evidence & What is still untested \\
\midrule
(\ref{claim:dag}) live graph, no recompile & DAG evaluation/rewiring is implemented and exercised continuously
during development (\S\ref{sec:named-mappings}) & whether a performer other than the author can
rewire it unaided \\
(\ref{claim:presets}) 11 mappings as presets & Table~\ref{tab:preset-nodes}: all eleven hand-built mappings rebuilt as presets from the
same catalog & whether a mapping designed independently of the catalog fits without a new
primitive \\
(\ref{claim:facing}) magnetometer-free facing & derivation is implemented and used throughout development sessions
& drift has not been measured against a ground-truth heading; bounded to short sessions by
assumption, not measurement \\
(\ref{claim:calibration}) mount-agnostic calibration & the correction transform is mount-independent by construction
(\S\ref{sec:limitations}) & not yet tested across multiple physical mount positions on hardware \\
\bottomrule
\end{tabular}
\end{table}
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

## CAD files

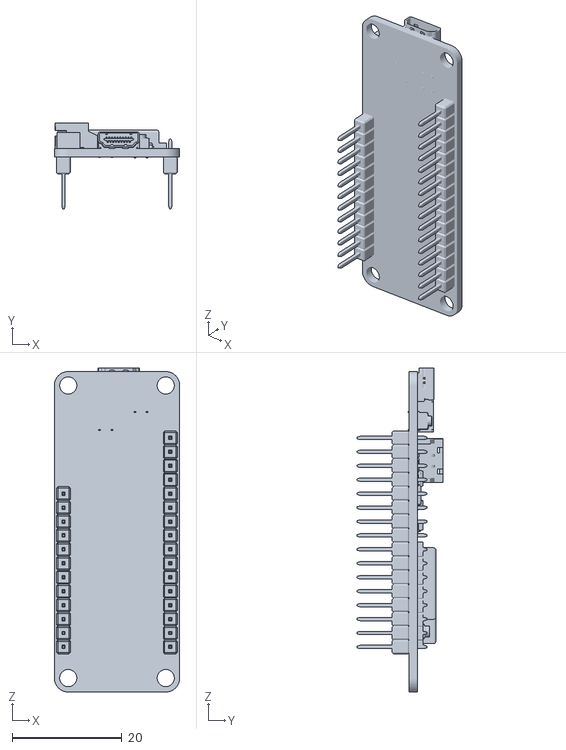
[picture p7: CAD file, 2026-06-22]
hardware/Assets/Sparkfun Thing Plus v8.stl
22.9 x 15.6 x 59.1

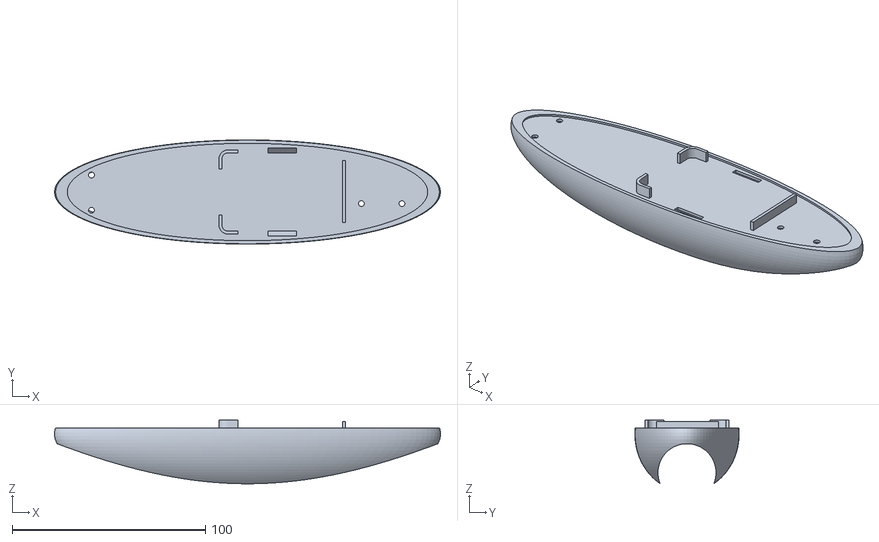
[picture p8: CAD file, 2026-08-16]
hardware/PRINTABLE/base_f.stl
199.9 x 54.0 x 32.9

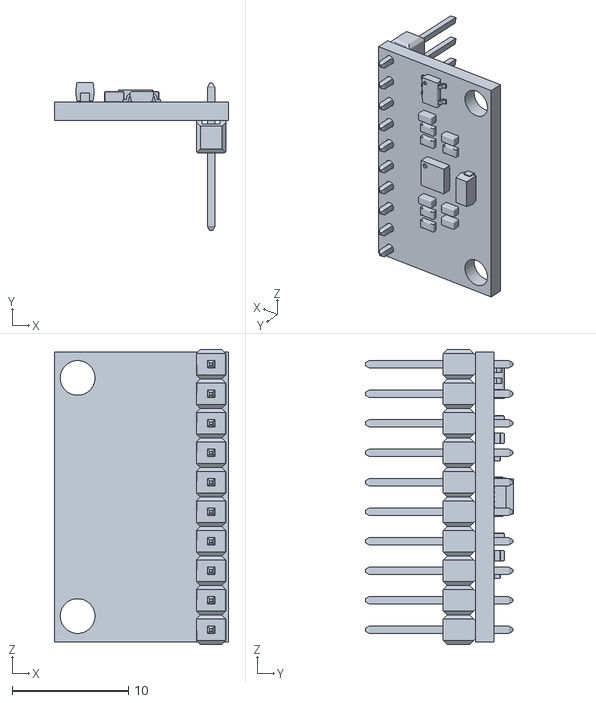
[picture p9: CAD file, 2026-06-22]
hardware/Assets/MPU-9250.stl
15.0 x 12.8 x 25.4

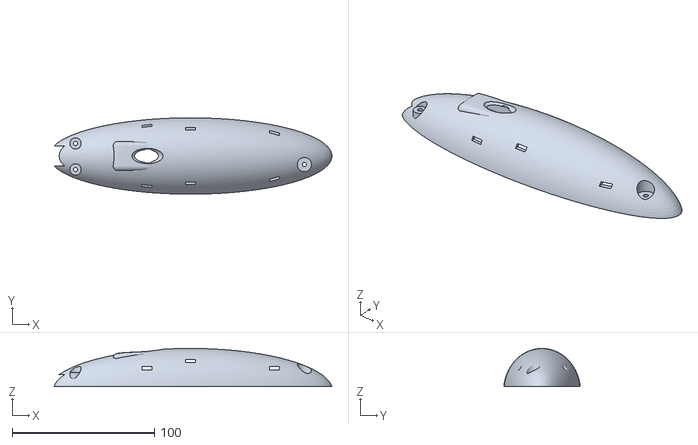
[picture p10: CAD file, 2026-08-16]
hardware/PRINTABLE/cap_f.stl
195.3 x 53.7 x 26.8

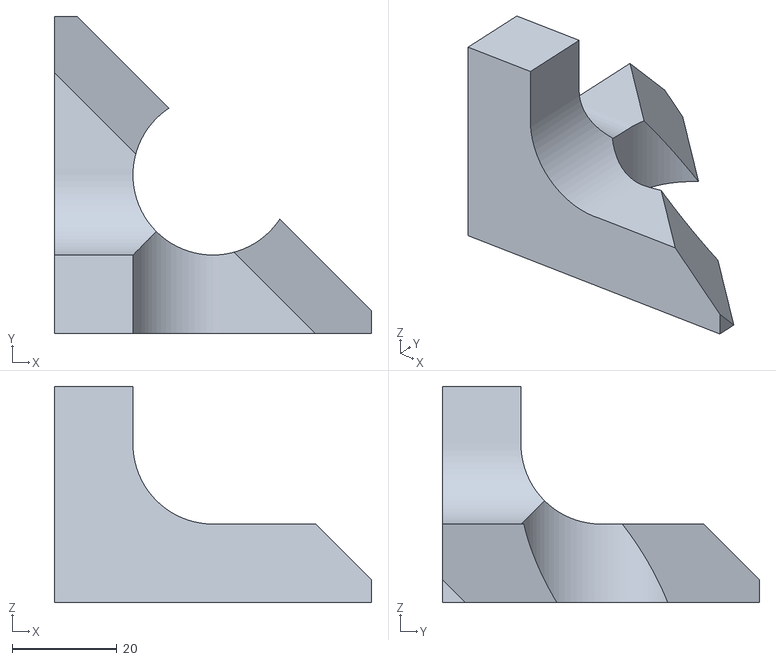
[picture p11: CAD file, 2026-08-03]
hardware/PRINTABLE/calibration_stand.stl
60.6 x 60.6 x 41.3

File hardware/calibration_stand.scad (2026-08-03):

$fn = 80;

staff_diameter = 30;    // staff diameter, mm
fit_clearance  = 0.6;   // total diametral clearance for a comfortable slip fit
wall           = 15;    // wall thickness left around each hole

staff_hole_d = staff_diameter + fit_clearance;
staff_hole_r = staff_hole_d / 2;
cube_size    = staff_hole_d + 2 * wall;

module calibration_cube() {
    difference() {
        cube([cube_size, cube_size, cube_size], center = true);
        rotate([0, 90, 0]) cylinder(r = staff_hole_r, h = cube_size + 2, center = true); // X
        rotate([90, 0, 0]) cylinder(r = staff_hole_r, h = cube_size + 2, center = true); // Y
        cylinder(r = staff_hole_r, h = cube_size + 2, center = true);                    // Z
    }
}

tetra_angle = 54.7356;

module horizontal_cut() {
    translate([-cube_size/2 - 1, -cube_size/2 - 1, -cube_size/2 - 1])
        cube([cube_size + 2, cube_size + 2, cube_size/2 + 1]);
}
module horizontal_cut_2() {
    translate([-1, -50, -cube_size/4 - 0.1])
        cube([cube_size + 2, cube_size + 2, cube_size/2 + 1]);


    translate([-50, -1, -cube_size/4 - 0.1])
        cube([cube_size + 2, cube_size + 2, cube_size/2 + 1]);
}

module diagonal_cut() {
    rotate(a = tetra_angle, v = [-1, 1, 0])
        translate([-1000, -1000, -1015])
            cube([2000, 2000, 1000]);
}

union() {
    difference() {
        intersection() {
            calibration_cube();
            horizontal_cut();
            diagonal_cut();
        }
        horizontal_cut_2();
    }
    translate([-cube_size/2, -cube_size/2]) cube([wall, wall, 11]);
}

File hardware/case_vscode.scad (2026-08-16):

preview_lift_cap = 15;
preview_cut = 0;
render_mode = "all"; // ["all", "cap", "base", "none"]
show_all_ghosts           = false; // when checked, shows every ghost regardless of the checkboxes below
show_ghost_esp32          = true;
show_ghost_mpu            = true;
show_ghost_battery        = true;
show_ghost_staff          = true;
show_ghost_button         = true;

$fn = 100;
module __Customizer_Limit__ () {}
staff_diameter  = 30;       // Diameter of the staff in mm
case_length     = 200;
case_width      = 54;
case_height     = 30;
wall_thickness  = 0.06;
strap_width     = 7;        // Width of the strap
strap_thickness = 2.2;        // Thickness of the strap
screw_d         = 1.5;      // Diameter of the screw holes
screw_head_d    = screw_d * 2 + 1;

// STL IMPORT POSITIONS
esp32_file  = "Assets/Sparkfun Thing Plus v8.stl";
esp32_pos   = [-85, 11.5, -2];
esp32_rot   = [90, 0, 270];
// Raw STL bounding box (native axes) is 22.86 x 15.59 x 59.06mm;
// rescale to the real board size (23.5 x 65mm) without touching the file.
esp32_target_width  = 23.5;
esp32_target_length = 65;
esp32_raw_width     = 22.860000610351562; // native X, becomes case-width axis after rotation
esp32_raw_length    = 59.06365966796875;  // native Z, becomes case-length axis after rotation
esp32_scale = [esp32_target_width / esp32_raw_width, 1, esp32_target_length / esp32_raw_length];
esp32_screw_x = -80.8;
esp32_screw_y_1 = -9.5;
esp32_screw_y_2 = 8.8;

mpu_file    = "Assets/MPU-9250.stl";
mpu_pos     = [57, 7, 3];
mpu_rot     = [90, 0, 90];
mpu_screw_y = -6;
mpu_screw_x_1 = 59;
mpu_screw_x_2 = 80;

staff_pos = [20, 0, -case_length/2 - 50];
staff_rot = [0, 90, 0];

button_pos = [-30-22.5, -8, 13.8];
button_rot = [0, 0, 0];

// LIPO BATTERY BOX (ghost) + CORNER SUPPORTS
battery_box_pos      = [18, 0, 7];
battery_box_size     = [62, 40, 6.5];
battery_box_corner_r = 3;

battery_support_leg       = 10;
battery_support_wall      = 1.5;
battery_support_clearance = 0.3;
battery_support_height    = 5;

battery_strap_slot_x_width = 15;
battery_strap_slot_y_width = 2.5;
battery_strap_x = battery_box_pos[0] - battery_strap_slot_x_width/2;
battery_strap_y = [
    battery_box_pos[1] - battery_box_size[1]/2 - 2.7,
    battery_box_pos[1] + battery_box_size[1]/2 + 0.3
];

module rounded_rect_2d(half_x, half_y, r) {
    hull() {
        for (sx = [-1, 1])
            for (sy = [-1, 1])
                translate([sx * (half_x - r), sy * (half_y - r)])
                    circle(r = r);
    }
}

module lipo_battery_ghost(size = battery_box_size, corner_r = battery_box_corner_r) {
    linear_extrude(height = size[2], center = true)
        rounded_rect_2d(size[0]/2, size[1]/2, corner_r);
}

module battery_corner_supports() {
    inner_half_x = battery_box_size[0]/2 + battery_support_clearance;
    inner_half_y = battery_box_size[1]/2 + battery_support_clearance;
    outer_half_x = inner_half_x + battery_support_wall;
    outer_half_y = inner_half_y + battery_support_wall;
    inner_r = battery_box_corner_r + battery_support_clearance;
    outer_r = inner_r + battery_support_wall;
    leg = battery_support_leg;

    floor_overlap = 0.4;

    translate([battery_box_pos[0], battery_box_pos[1], strap_thickness - floor_overlap]) {
        linear_extrude(height = battery_support_height + floor_overlap) {
            intersection() {
                difference() {
                    rounded_rect_2d(outer_half_x, outer_half_y, outer_r);
                    rounded_rect_2d(inner_half_x, inner_half_y, inner_r);
                }
                union() {
                    for (sy = [-1, 1])
                        translate([-1 * (outer_half_x - leg/2), sy * (outer_half_y - leg/2)])
                            square([leg, leg], center = true);
                }
            }
        }
        translate([outer_half_x - 1.5, -outer_half_y + 6])
            cube([battery_support_wall, 32, strap_thickness*2 + floor_overlap]);
    }
}

// IMPORT GHOSTS
if (show_all_ghosts || show_ghost_esp32)
    % color("green", 0.3) translate(esp32_pos)   rotate(esp32_rot)   scale(esp32_scale) import(esp32_file);
if (show_all_ghosts || show_ghost_mpu)
    % color("green", 0.3) translate(mpu_pos)     rotate(mpu_rot)     import(mpu_file);
if (show_all_ghosts || show_ghost_battery)
    % color("green", 0.3) translate(battery_box_pos) lipo_battery_ghost();
if (show_all_ghosts || show_ghost_staff)
    % color("green", 0.3) rotate(staff_rot) translate(staff_pos) cylinder(r = staff_diameter/2, h = case_length + 100);
if (show_all_ghosts || show_ghost_button)
    % color("green", 0.3) translate(button_pos) rotate(button_rot) button_cap();

// FULL GEOMETRY MODULE
module raw_uncut_case() {
    union() {
        // Floor
        intersection() {
            scale([case_length/2, case_width/2, case_height]) {
                sphere(r = 1 - wall_thickness);
            }
            translate([-case_length/2, -case_width/2, 1]) {
                cube([case_length, case_width, strap_thickness-1]);
            }
        }

        // Walls
        difference() {
            scale([case_length/2, case_width/2, case_height]) {
                sphere(r = 1);
            }
            scale([case_length/2, case_width/2, case_height]) {
                sphere(r = 1 - wall_thickness);
            }
        }
    }
}

// BUTTON MODULE
module button_cap() {
    difference() {
        minkowski() {
            intersection() {
                translate([1.5, 1.25, 1.5])
                cube([45 - 3, 16.5 - 3, 13 - 3]);

                translate([22.5, 8, -178])
                sphere(r = 190 - 1.5);
            }
            sphere(r = 1.5);
        }
        translate([22.5, 8, 11.5]) cylinder(r = 4.5, h = 3);
    }
    translate([22.5, 8, 11.2]) cylinder(r = 4.25, h = 0.8);
    translate([22.5, 8, 12]) cylinder(r = 2.25, h = 2.5);
}

module button_cap_boss(margin = 2) {
    minkowski() {
        intersection() {
            translate([1.5, 1.25, 1.5])
            cube([45 - 3, 16.5 - 3, 13 - 3]);

            translate([22.5, 8, -178])
            sphere(r = 190 - 1.5);
        }
        sphere(r = 1.5 + margin);
    }
}

module button_socket(clearance = 0.5, side_relief = 3) {
    union() {
        minkowski() {
            intersection() {
                translate([1.5, 1.25, 1.5])
                cube([45 - 3, 16.5 - 3, 13 - 3]);

                translate([22.5, 8, -178])
                sphere(r = 190 - 1.5);
            }
            sphere(r = 1.5 + clearance);
        }

        translate([-side_relief, -side_relief, -4])
            cube([45 + 2 * side_relief, 16 + 2 * side_relief, 8]);
    }
}

// HOLES MODULE
module standard_hole_cuts(draw_button_shere = false) {
    // Staff
    rotate([0, 90, 0]) {
        translate([20, 0, -case_length/2 - 15]) {
            cylinder(r = staff_diameter/2, h = case_length + 30);
        }
    }

    // Strap Slots
    strap_offset_x = case_length / 9 * 2.5;

    translate([strap_offset_x, -case_width/2, case_height/2])
        cube([strap_width, case_width, strap_thickness]);

    translate([-case_length/4 + 16, -case_width/2, case_height/2])
        cube([strap_width, case_width, strap_thickness]);

    translate([-strap_width/2, -case_width/2, case_height/3*2])
        cube([strap_width, case_width, strap_thickness]);

    // Screws Holes
    // ESP
    translate([esp32_screw_x, esp32_screw_y_1, -5]) cylinder(r = screw_d, h = 30);
    translate([esp32_screw_x, esp32_screw_y_2, -5])  cylinder(r = screw_d, h = 30);
    // MPU
    translate([mpu_screw_x_1, mpu_screw_y, -5])    cylinder(r = screw_d, h = 20);
    translate([mpu_screw_x_2, mpu_screw_y, -5])    cylinder(r = screw_d, h = 30);
    // Battery strap slots (through the floor, either side of the battery)
    for (y = battery_strap_y)
        translate([battery_strap_x, y, -1])
            cube([battery_strap_slot_x_width, battery_strap_slot_y_width, 12]);

    translate([esp32_screw_x, esp32_screw_y_1, 13]) cylinder(r = screw_head_d, h = 9);
    translate([esp32_screw_x, esp32_screw_y_2, 13])  cylinder(r = screw_head_d, h = 8);
    translate([mpu_screw_x_2, mpu_screw_y, 12])    cylinder(r = screw_head_d+1, h = 100);

    // button
    translate([button_pos[0]+22.5, 0, 16])    cylinder(r = screw_head_d + 1, h = 15);
    scale([2, 1, 1.2]) translate([button_pos[0]+37, 0, 26]) sphere(r = screw_head_d+2);
    // Cable pass-through
    translate([button_pos[0]-3, -3.5, 16]) cube([3, 7, 5]);
    translate([-8,  -3.5, 16]) cube([3, 7, 5]);

    translate(button_pos) rotate(button_rot) button_socket();
}

module screw_reinforcements() {
    union() {
        intersection() {
            scale([case_length/2, case_width/2, case_height]) {
                sphere(r = 1);
            }
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

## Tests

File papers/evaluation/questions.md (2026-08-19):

# REMORA Evaluation Questions

| # | Section | Question | Type | 1 means | 5 means |
|---|---|---|---|---|---|
| 1 | Background | Martial arts, staff/baton, or weapon-form experience (bo, kali, fencing, twirling...) | Scale 1–5 | No experience | Extensive experience |
| 2 | Background | General music experience (playing, composing, improvising...) | Scale 1–5 | No experience | Extensive experience |
| 3 | Background | Motion-controlled or gestural digital instrument experience (theremin, Kinect, Leap Motion, wearable sensors...) | Scale 1–5 | No experience | Extensive experience |
| 4 | Playing experience | I felt in control of the sound, and could predict how my movements would affect it | Scale 1–5 | Not in control, no idea what my movements would do | Fully in control, always knew what my movements would do |
| 5 | Playing experience | Playing the instrument felt physically comfortable | Scale 1–5 | Very uncomfortable | Very comfortable |
| 6 | Playing experience | The instrument offered me interesting, new ways to make sound | Scale 1–5 | No new possibilities | Many new possibilities |
| 7 | Playing experience | I felt able to express myself musically through movement | Scale 1–5 | Not expressive at all | Very expressive |
| 8 | Playing experience | As I kept playing, I thought less about "how do I do this" and more about the music itself | Scale 1–5 | I was thinking about the mechanics the whole time | I stopped thinking about the mechanics entirely |
| 9 | Playing experience | I felt I could make music I found satisfying, and felt physically expressive while playing | Scale 1–5 | Strongly disagree | Strongly agree |
| 10 | Preset | Which preset did you prefer overall? | Multiple choice (6 presets + other) | — | — |
| 11 | Preset | Why? | Open text | — | — |
| 12 | Reflection | Did you experience moments of frustration? Did it feel like a normal, motivating part of learning, or did it make you want to stop? | Open text | — | — |
| 13 | Reflection | What's the one thing you'd change first? | Open text | — | — |

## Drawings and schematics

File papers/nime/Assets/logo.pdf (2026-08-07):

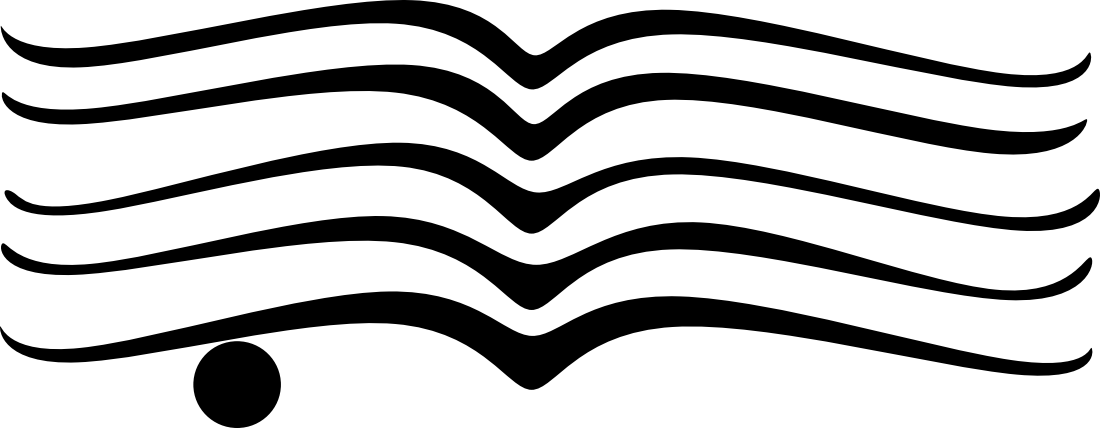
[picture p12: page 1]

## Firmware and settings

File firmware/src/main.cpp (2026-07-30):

#include <Arduino.h>
#include <WiFi.h>
#include <WiFiUdp.h>
#include <Wire.h>
#include <OSCMessage.h>
#include "MPU9250.h"

// Network Configuration
const char *WIFI_SSID = "MUSIC-TIM";
const char *WIFI_PASSWORD = "T8329#n5";

WiFiUDP Udp;
const IPAddress outIp(192, 168, 12, 1);
const uint16_t outPort = 8000;
const uint16_t localPort = 8888;

MPU9250 mpu;

#define SEND_INTERVAL_MS 10 // 100 Hz transmission rate
#define LED_PIN 13          // Blue STAT LED

// WiFi
void connectWiFi() {
  Serial.println("\n--- ESP32-S2 WiFi Connection ---");
  WiFi.mode(WIFI_STA);
  WiFi.setSleep(false);
  WiFi.begin(WIFI_SSID, WIFI_PASSWORD);

  Serial.printf("Connecting to: %s\n", WIFI_SSID);

  uint8_t attempts = 0;
  bool ledState = false;
  while (WiFi.status() != WL_CONNECTED) {
    ledState = !ledState;
    digitalWrite(LED_PIN, ledState); // Blink while not connected
    delay(500);
    Serial.print('.');
    if (++attempts >= 40) {
      Serial.println("\n[Timeout] Retrying...");
      WiFi.disconnect(true);
      delay(1000);
      WiFi.begin(WIFI_SSID, WIFI_PASSWORD);
      attempts = 0;
    }
  }

  digitalWrite(LED_PIN, HIGH);

  Serial.println("\n=========================================");
  Serial.println("SUCCESS: CONNECTED");
  Serial.print("IP   : ");
  Serial.println(WiFi.localIP());
  Serial.println("=========================================\n");
}

void setup() {
  Serial.begin(115200);

  uint32_t tStart = millis();
  while (!Serial && (millis() - tStart < 5000)) delay(10);

  Serial.println("\n\n=========================================");
  Serial.println("ESP32-S2 IS BOOTING... (MPU-9250 version)");
  Serial.println("=========================================\n");

  pinMode(LED_PIN, OUTPUT);
  digitalWrite(LED_PIN, LOW); // Start with LED off

  Wire.begin(1, 2);
  Wire.setClock(400000);
  Wire.setTimeOut(20);

  Serial.print("Initializing MPU-9250... ");
  mpu.setup(0x68);
  Serial.println("OK");

  connectWiFi();

  Udp.begin(localPort);

  String ipStr = WiFi.localIP().toString();
  OSCMessage msg("/esp32/connected");
  msg.add(ipStr.c_str());
  Udp.beginPacket(outIp, outPort);
  msg.send(Udp);
  Udp.endPacket();

  Serial.println("\nSetup complete - streaming at 50 Hz");
}

void loop() {
  if (WiFi.status() != WL_CONNECTED) {
    Serial.println("WiFi lost - reconnecting...");
    connectWiFi();
    return;
  }

  if (mpu.update()) {
    static uint32_t lastUpdate = 0;
    const uint32_t now = millis();

    // Only transmit at the desired interval (100 Hz)
    if (now - lastUpdate >= SEND_INTERVAL_MS) {
      lastUpdate = now;

    // Get Accel/Gyro/Mag values (floats)
    float ax = mpu.getAccX();
    float ay = mpu.getAccY();
    float az = mpu.getAccZ();

    float gx = mpu.getGyroX();
    float gy = mpu.getGyroY();
    float gz = mpu.getGyroZ();

    float mx = mpu.getMagX();
    float my = mpu.getMagY();
    float mz = mpu.getMagZ();

    // Get Quaternion (calculated internally by the library)
    float qw = mpu.getQuaternionW();
    float qx = mpu.getQuaternionX();
    float qy = mpu.getQuaternionY();
    float qz = mpu.getQuaternionZ();

    // Build & Send OSC
    OSCMessage msg("/esp32/imu");
    msg.add(ax).add(ay).add(az);
    msg.add(gx).add(gy).add(gz);
    msg.add(mx).add(my).add(mz);
    msg.add(qw).add(qx).add(qy).add(qz);
    msg.add(WiFi.localIP().toString().c_str());

    Udp.beginPacket(outIp, outPort);
    msg.send(Udp);
    Udp.endPacket();
    }
  }
}

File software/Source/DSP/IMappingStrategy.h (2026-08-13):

#pragma once

#include "MathHelpers.h"
#include <JuceHeader.h>
#include <atomic>
#include <memory>
#include <vector>

struct StaffSoundParams;

// Everything the Additive Synth engine needs, written by the single "sink.additiveSynth" mega-node.
struct AdditiveSynthParams {
    float rootHz = 110.0f;
    // All voices sing the same pitch as voice 0 by default (no chord).
    float chordSemitones[3] = { 0.0f, 0.0f, 0.0f };
    int numVoices = 1;

    // Only voice 0 sounds by default; voices 1-3 are silent until a preset opts them in.
    float voiceGain[4] = { 1.0f, 0.0f, 0.0f, 0.0f };

    // Fundamental only by default - a pure sine tone until a preset adds harmonics.
    float partialAmps[6] = { 1.0f, 0.0f, 0.0f, 0.0f, 0.0f, 0.0f };
    float driveAmt = 0.0f;

    float vibratoDepth = 0.0f;
    float vibratoRateHz = 5.0f;
    float tremoloDepth = 0.0f;
    float tremoloRateHz = 4.0f;

    float noiseAmount = 0.0f;
    float noiseLpCoef = 0.5f;
    bool  usePinkNoise = false;

    // Panning disabled by default - equal gain to both channels for every voice.
    float panL[4] = { 0.5f, 0.5f, 0.5f, 0.5f };
    float panR[4] = { 0.5f, 0.5f, 0.5f, 0.5f };

    float lpfCutoffHz = 20000.0f;

    bool  useIndependentVoicePitch = false;
    float voiceHz[4] = { 110.0f, 110.0f, 110.0f, 110.0f };

    float reverbWetLevel = 0.0f;   // 0 = dry/bypassed, 1 = fully wet
    float reverbRoomSize = 0.5f;   // decay length ("feedback"): 0 = short, 1 = long
    float reverbDamping  = 0.5f;   // high-frequency absorption: 0 = bright, 1 = dark
};

// Everything the Granular Synth engine needs, written by the single "sink.granularSynth" mega-node.
// `level` defaults to 0 (silent) so presets that don't wire this node leave the engine inaudible.
struct GranularSynthParams {
    float positionNorm = 0.0f;    // 0-1, scan position in the internal source buffer
    float positionSpray = 0.0f;   // 0-1, random jitter added to position per grain
    float grainSizeMs = 60.0f;    // 5-500
    float densityHz = 20.0f;      // 1-200 grains/sec
    float pitchSemitones = 0.0f;  // -24..24, grain playback pitch
    float pitchSpray = 0.0f;      // 0-12 semitones, random jitter per grain
    float panSpread = 0.0f;       // 0-1, stereo spread of grains
    float ampSpray = 0.0f;        // 0-1, random amplitude jitter per grain
    float level = 0.0f;           // 0-1, engine output trim
    float reverseAmount = 0.0f;   // 0-1, probability a grain plays reversed
};

// Everything the Pink Trombone (vocal tract) engine needs, written by the single
// "sink.pinkTromboneSynth" mega-node. `level` defaults to 0 (silent) so presets that don't wire
// this node leave the engine inaudible.
struct PinkTromboneParams {
    float frequencyHz = 140.0f;         // 40-600, glottal pitch
    float tenseness = 0.6f;             // 0-1, vocal fold tension: breathy (low) to pressed (high)
    float tongueIndexNorm = 0.5f;       // 0-1, front-back tongue position along its allowed range
    float tongueDiameter = 2.75f;       // ~1.5-3.5, tongue height: smaller = narrower/raised, larger = wider/lowered
    float constrictionIndexNorm = 0.5f; // 0-1, position along the tract of an extra constriction
    float constrictionDiameter = 4.0f;  // 0-4, diameter of that constriction; >= ~3.7 is a no-op (open)
    float fricativeIntensity = 0.0f;    // 0-1, turbulence noise injected at the constriction
    float level = 0.0f;                 // 0-1, engine output trim
};

// Written once per audio block by whichever mega-sink nodes the active preset's graph wires up.
// `masterGain` is shared by every engine (written by "sink.generalGain"); each engine param struct
// defaults to silent/off so an engine a preset never wires stays inaudible.
struct MappingOutput {
    float masterGain = 0.0f;
    AdditiveSynthParams additive;
    GranularSynthParams granular;
    PinkTromboneParams pinkTrombone;
    bool additiveActive = false;
    bool granularActive = false;
    bool pinkTromboneActive = false;
};
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

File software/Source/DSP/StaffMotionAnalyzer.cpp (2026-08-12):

#include "StaffMotionAnalyzer.h"
#include "SynthManager.h"
#include "../UI/DebugLog.h"
#include <algorithm>
#include <cmath>

StaffMotionAnalyzer::DerivedMotionFrame StaffMotionAnalyzer::computeFrame(const StaffSoundParams& input_parameters) {
    DerivedMotionFrame frame;

    calculateDeltaTime();
    frame.deltaTimeSeconds = delta_time_seconds_;

    float tip_x, tip_y, tip_z;
    updateTipPositionHistory(input_parameters, tip_x, tip_y, tip_z);
    frame.tipX = tip_x;
    frame.tipY = tip_y;

    calculateRotationAxisAtMidpoint(frame.rotationAxisX, frame.rotationAxisY, frame.rotationAxisZ);

    updateGravityVector(input_parameters);

    float dynamic_accel_x, dynamic_accel_y, dynamic_accel_z, dynamic_accel_magnitude;
    calculateDynamicAcceleration(input_parameters, dynamic_accel_x, dynamic_accel_y, dynamic_accel_z, dynamic_accel_magnitude);

    float velocity_magnitude = integrateVelocityForLabanWeight(dynamic_accel_x, dynamic_accel_y, dynamic_accel_z);

    const float gyroscope_magnitude = std::sqrt(input_parameters.gx * input_parameters.gx + input_parameters.gy * input_parameters.gy + input_parameters.gz * input_parameters.gz);
    frame.gyroscopeMagnitude = gyroscope_magnitude;
    frame.smoothedGyroscopeMagnitude = updateGyroscopeMagnitude(gyroscope_magnitude);

    detectAxialThrustPeaks(input_parameters, dynamic_accel_x, dynamic_accel_y, dynamic_accel_z, tip_x, tip_y, tip_z, gyroscope_magnitude);
    frame.axialThrustPeakEnvelope = axialThrustPeakEnvelope();

    frame.labanWeight = updateLabanWeight(velocity_magnitude);
    frame.labanTimeSuddenness = updateLabanTime(gyroscope_magnitude);
    frame.labanSpaceFocus = updateLabanSpace(input_parameters, gyroscope_magnitude);
    updateLabanFlow(dynamic_accel_magnitude, frame.labanFlowBound, frame.labanFlowFree);

    frame.isMoving = frame.smoothedGyroscopeMagnitude > kGyroscopeFloor;

    return frame;
}

void StaffMotionAnalyzer::prepare() {
    delta_time_seconds_ = 1.0f / 100.0f;
    last_timestamp_ticks_ = 0;

    gravity_x_ = 0.f; gravity_y_ = 0.f; gravity_z_ = 1.f;
    velocity_x_  = 0.f; velocity_y_  = 0.f; velocity_z_  = 0.f;

    weight_envelope_ = 0.f;
    previous_gyroscope_magnitude_ = 0.f;
    suddenness_ = 0.f;
    suddenness_envelope_ = 0.f;

    previous_gyroscope_direction_x_ = 0.f; previous_gyroscope_direction_y_ = 0.f; previous_gyroscope_direction_z_ = 1.f;
    axis_focus_ = 1.f;

    previous_dynamic_acceleration_magnitude_ = 0.f;
    flow_bound_envelope_ = 0.f;

    smoothed_gyroscope_magnitude_ = 0.f;

    for (int i = 0; i < 3; ++i) {
        tip_position_x_history_[i] = 1.f;
        tip_position_y_history_[i] = 0.f;
        tip_position_z_history_[i] = 0.f;
    }

    smoothed_rotation_axis_x_ = 0.f;
    smoothed_rotation_axis_y_ = 0.f;
    smoothed_rotation_axis_z_ = 1.f;

    smoothed_forward_axis_x_ = 1.f;
    smoothed_forward_axis_y_ = 0.f;

    is_rotation_axis_vertical_ = false;
    rotation_spin_direction_  = 1.f;
    was_rotation_axis_vertical_ = false;
    previous_rotation_spin_direction_ = 1.f;

    reference_azimuth_x_ = 1.f;
    reference_azimuth_y_ = 0.f;
    is_reference_azimuth_set_ = false;

    is_facing_north_ = true;
    previous_is_facing_north_ = true;

    accumulated_spin_degrees_ = 0.f;
    continuous_spin_count_ = 0;

    axial_thrust_peak_envelope_ = 0.f;
    previous_axial_acceleration_ = 0.f;
    previous_axial_jerk_ = 0.f;
    thrust_cooldown_seconds_ = 0.f;
}

void StaffMotionAnalyzer::calculateDeltaTime() {
    const juce::int64 current_time_ticks = juce::Time::getHighResolutionTicks();
    if (last_timestamp_ticks_ != 0) {
        double elapsed_seconds = juce::Time::highResolutionTicksToSeconds(current_time_ticks - last_timestamp_ticks_);
        if (elapsed_seconds > 0.0001 && elapsed_seconds < 0.2) {
            delta_time_seconds_ = static_cast<float>(elapsed_seconds);
        }
    }
    last_timestamp_ticks_ = current_time_ticks;
}

void StaffMotionAnalyzer::updateTipPositionHistory(const StaffSoundParams& input_parameters, float& current_tip_x, float& current_tip_y, float& current_tip_z) {
    MathHelpers::rotateVectorByQuaternion(input_parameters.qw, input_parameters.qx, input_parameters.qy, input_parameters.qz, 1.f, 0.f, 0.f, current_tip_x, current_tip_y, current_tip_z);

    // shift ring buffer: [2]=oldest, [1]=mid, [0]=newest
    tip_position_x_history_[2] = tip_position_x_history_[1]; tip_position_x_history_[1] = tip_position_x_history_[0]; tip_position_x_history_[0] = current_tip_x;
    tip_position_y_history_[2] = tip_position_y_history_[1]; tip_position_y_history_[1] = tip_position_y_history_[0]; tip_position_y_history_[0] = current_tip_y;
    tip_position_z_history_[2] = tip_position_z_history_[1]; tip_position_z_history_[1] = tip_position_z_history_[0]; tip_position_z_history_[0] = current_tip_z;
}

void StaffMotionAnalyzer::calculateRotationAxisAtMidpoint(float& axis_x, float& axis_y, float& axis_z) const {
    // velocity_mean = (position[0] - position[2]) / 2 (central difference, 1-frame latency)
    float velocity_mean_x = (tip_position_x_history_[0] - tip_position_x_history_[2]) * 0.5f;
    float velocity_mean_y = (tip_position_y_history_[0] - tip_position_y_history_[2]) * 0.5f;
    float velocity_mean_z = (tip_position_z_history_[0] - tip_position_z_history_[2]) * 0.5f;

    // axis = position[1] cross_product velocity_mean (rotation axis at midpoint)
    axis_x = tip_position_y_history_[1] * velocity_mean_z - tip_position_z_history_[1] * velocity_mean_y;
    axis_y = tip_position_z_history_[1] * velocity_mean_x - tip_position_x_history_[1] * velocity_mean_z;
    axis_z = tip_position_x_history_[1] * velocity_mean_y - tip_position_y_history_[1] * velocity_mean_x;
}

void StaffMotionAnalyzer::updateGravityVector(const StaffSoundParams& input_parameters) {
    float gravity_x_temp, gravity_y_temp, gravity_z_temp;
    MathHelpers::rotateVectorByQuaternion(input_parameters.qw, -input_parameters.qx, -input_parameters.qy, -input_parameters.qz, 0.f, 0.f, 1.f, gravity_x_temp, gravity_y_temp, gravity_z_temp);
    constexpr float kGravitySmoothingAlpha = 0.10f; // Time Constant approx 90ms
    gravity_x_ = MathHelpers::applyOnePoleFilter(gravity_x_, gravity_x_temp, kGravitySmoothingAlpha);
    gravity_y_ = MathHelpers::applyOnePoleFilter(gravity_y_, gravity_y_temp, kGravitySmoothingAlpha);
    gravity_z_ = MathHelpers::applyOnePoleFilter(gravity_z_, gravity_z_temp, kGravitySmoothingAlpha);
}

void StaffMotionAnalyzer::calculateDynamicAcceleration(const StaffSoundParams& input_parameters, float& dynamic_accel_x, float& dynamic_accel_y, float& dynamic_accel_z, float& dynamic_accel_magnitude) const {
    dynamic_accel_x = input_parameters.ax - gravity_x_;
    dynamic_accel_y = input_parameters.ay - gravity_y_;
    dynamic_accel_z = input_parameters.az - gravity_z_;
    dynamic_accel_magnitude = std::sqrt(dynamic_accel_x * dynamic_accel_x + dynamic_accel_y * dynamic_accel_y + dynamic_accel_z * dynamic_accel_z);
}
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

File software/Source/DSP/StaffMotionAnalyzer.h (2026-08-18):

#pragma once

#include "MathHelpers.h"
#include <JuceHeader.h>

struct StaffSoundParams;

// Shared engine every mapping composes, so only the signal-to-sound logic differs between mappings.
class StaffMotionAnalyzer {
public:
    static constexpr float kGyroscopeFloor = 30.0f;
    static constexpr float kGyroscopeCeiling = 750.0f;

    // Only one of these may run per block - both write the same shared state.
    enum class SpinConvention { ByAbsoluteComponent, ByReferenceAzimuth };

    // Excludes spin classification/facing/continuous-spin-count - the Graph Spin Classification node calls those directly.
    struct DerivedMotionFrame {
        float deltaTimeSeconds = 1.0f / 100.0f;
        float gyroscopeMagnitude = 0.f;
        float smoothedGyroscopeMagnitude = 0.f;
        float labanWeight = 0.f;
        float labanTimeSuddenness = 0.f;
        float labanSpaceFocus = 0.f;
        float labanFlowBound = 0.f;
        float labanFlowFree = 0.f;
        bool  isMoving = false;
        float axialThrustPeakEnvelope = 0.f;
        float rotationAxisX = 0.f, rotationAxisY = 0.f, rotationAxisZ = 1.f;
        float tipX = 1.f, tipY = 0.f;
    };

    // Single source of truth for the pipeline every mapping used to duplicate.
    DerivedMotionFrame computeFrame(const StaffSoundParams& input_parameters);

    void prepare();

    void calculateDeltaTime();
    float deltaTimeSeconds() const noexcept { return delta_time_seconds_; }

    // Also doubles as the staff's facing vector during horizontal-plane spins.
    void updateTipPositionHistory(const StaffSoundParams &input_parameters,
                                   float &current_tip_x, float &current_tip_y,
                                   float &current_tip_z);
    void calculateRotationAxisAtMidpoint(float &axis_x, float &axis_y,
                                          float &axis_z) const;

    void updateGravityVector(const StaffSoundParams &input_parameters);
    void calculateDynamicAcceleration(const StaffSoundParams &input_parameters,
                                       float &dynamic_accel_x,
                                       float &dynamic_accel_y,
                                       float &dynamic_accel_z,
                                       float &dynamic_accel_magnitude) const;
    float integrateVelocityForLabanWeight(float dynamic_accel_x,
                                           float dynamic_accel_y,
                                           float dynamic_accel_z);

    void detectAxialThrustPeaks(const StaffSoundParams &input_parameters,
                                 float dynamic_accel_x, float dynamic_accel_y,
                                 float dynamic_accel_z, float tip_x,
                                 float tip_y, float tip_z,
                                 float gyroscope_magnitude);
    float axialThrustPeakEnvelope() const noexcept {
        return axial_thrust_peak_envelope_;
    }

    float updateGyroscopeMagnitude(float gyroscope_magnitude);
    float smoothedGyroscopeMagnitude() const noexcept {
        return smoothed_gyroscope_magnitude_;
    }

    float updateLabanWeight(float velocity_magnitude);
    float updateLabanTime(float gyroscope_magnitude);
    float updateLabanSpace(const StaffSoundParams &input_parameters,
                            float gyroscope_magnitude);
    void updateLabanFlow(float dynamic_acceleration_magnitude,
                          float &flow_bound, float &flow_free);

    // Two interchangeable direction conventions: ByAbsoluteComponent (Azimut family) vs ByReferenceAzimuth (Martial family).
    bool updateSpinClassificationByAbsoluteComponent(float axis_x,
                                                       float axis_y,
                                                       float axis_z);
    bool updateSpinClassificationByReferenceAzimuth(float axis_x, float axis_y,
                                                      float axis_z);

    bool isRotationAxisVertical() const noexcept {
        return is_rotation_axis_vertical_;
    }
    float rotationSpinDirection() const noexcept {
        return rotation_spin_direction_;
    }
    float smoothedRotationAxisX() const noexcept {
        return smoothed_rotation_axis_x_;
    }
    float smoothedRotationAxisY() const noexcept {
        return smoothed_rotation_axis_y_;
    }

    // Hysteresis avoids chatter at the boundary; returns true on the block where facing changes.
    bool updateFacingClassification(float tip_x, float tip_y);
    bool isFacingNorth() const noexcept { return is_facing_north_; }

    // Resets whenever spin classification changes; used by mappings that sweep a parameter via continuous spinning.
    int accumulateContinuousSpins(bool spin_classification_changed,
                                   float gyroscope_magnitude);
    int continuousSpinCount() const noexcept { return continuous_spin_count_; }
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

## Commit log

2026-04-14 Add Karplus-Strong synthesis patch and related subpatch for string simulation + Add PlugData mockData utilities
    - Created a new patch `KarplusStrong.pd` implementing the Karplus-Strong algorithm using noise generation and various audio processing objects.
    - Introduced a subpatch for noise array manipulation and added controls for resonance, pitch, and damping.
    - Added a second patch `ma_corde.pd` for a string simulation with similar functionality, including MIDI to frequency conversion and audio effects.
    - Integrated controls for resonance and damping, along with a noise array for sound generation.
2026-06-04 JUCE: add calibration to sync real BO with virtual one
2026-06-04 JUCE UI: Raw Data button is now a toggle
2026-06-05 JUCE UI&DSP: Added a mute audio button
2026-06-08 JUCE: Add calibration but not working fine
2026-06-08 JUCE UI: Change calibration (not perfect)
2026-06-08 JUCE: Better calibration (not perfect => when rotating around the staff main axis it breaks everything)
2026-06-09 JUCE Calib: Better calibration around bo's long axis
2026-06-09 JUCE: Make switchable mappings with simple UI menu
2026-06-09 JUCE DSP: add spin filter mapping
2026-06-10 JUCE DSP BOZENDOMAP: Change pitch based on rotation plane and direction
2026-06-18 firmware: light blue led when running
2026-06-22 hardware: add hardware stls and case cad file
    [MPU-9250.stl, Sparkfun Thing Plus v8.stl, case_vscode.scad]
2026-06-22 casing: add a 3 strip hole
    [case_vscode.scad]
2026-06-23 casing: add plate for harward support
    [case_vscode.scad]
2026-06-23 casing: add opening for USB-C
    [case_vscode.scad]
2026-06-23 casing: add screw holes
    [case_vscode.scad]
2026-06-23 casing: change all to a one piece only case
    [case_vscode.scad]
2026-06-23 casing: seperate into BASE and CAP
    [BASE.stl, CAP.stl, base_print.scad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]
2026-06-24 casing: add screws reinforcements for screw head
    [case_vscode.scad]
2026-06-24 casing: new exports and small fixes
    [BASE.stl, CAP.stl, case_vscode.scad]
2026-06-26 casing: visual ghosts of staff
    [case_vscode.scad]
2026-06-26 casing: improve customization inside openscad visualizer
    [case_vscode.scad]
2026-06-29 GIT: update and simplify main readme
    [MPU-9250.stl, Sparkfun Thing Plus v8.stl, case_vscode.scad]
2026-06-29 casing: update stl files
    [BASE.stl, CAP.stl]
2026-06-29 casing: change dimension from the 1 printed prototype
    [case_vscode.scad]
2026-06-30 casing: multiple fixes (and add disabled poles)
    [BASE.stl, CAP.stl, case_vscode.scad]
2026-06-30 casing: multiple fixes from the 2nd printed prototype
    [case_vscode.scad]
2026-06-30 casing: fix sphere for button making a hole in the base
    [case_vscode.scad]
2026-07-09 casing: updatescrew holes & USB slot
    [CAP.stl, case_vscode.scad]
2026-07-09 casing: add slot for switch
    [CAP.stl, case_vscode.scad]
2026-07-09 JUCE: DSPwindows: add previous/next mapping buttons
2026-07-14 JUCE: Move FFT to a separate thread
2026-07-14 JUCE: update calibration UI to take almost all the screen
2026-07-14 JUCE UI: centralize button generation
2026-07-14 JUCE UI: change the calibration button to be simpler and remove calibration hint as it's already in the overlay
2026-07-15 JUCE: New mapping; merge simple pitch and azimut based on speed
2026-07-17 casing: add "none" rendering mode and make the usb hole bigger
    [case_vscode.scad]
2026-07-17 casing: better button support + add preview cut
    [case_vscode.scad]
2026-07-17 casing: better mpu screw holder
    [case_vscode.scad]
2026-07-17 casing: update printable cap file
    [CAP.stl]
2026-07-27 casing: fix button cutting cube limit
    [case_vscode.scad]
2026-07-27 casing: change to a lipo battery
    [case_vscode.scad]
2026-07-27 casing: enable export only the holder
    [case_vscode.scad]
2026-07-27 casing: change "both" to "all"
    [case_vscode.scad]
2026-07-27 casing: update corner of LiPo to not stuck with the cap
    [case_vscode.scad]
2026-07-27 casing: make everything wider to contains the battery
    [case_vscode.scad]
2026-07-27 casing: small clean
    [case_vscode.scad]
2026-07-27 casing: fix minor openscad issues
    [case_vscode.scad]
2026-07-28 casing: change how show ghost works and change esp32 to the real size
    [case_vscode.scad]
2026-07-28 casing: change screw support for ESP32
    [case_vscode.scad]
2026-07-28 casing: change battery holder to just a strap
    [case_vscode.scad]
2026-07-28 casing: add show all ghosts
    [case_vscode.scad]
2026-07-28 casing: change position of strap slot for the button
    [case_vscode.scad]
2026-07-30 casing: make the battery a little bigger
    [case_vscode.scad]
2026-07-30 JUCE CQ: Consolidate the duplicated gravity/velocity/gyroscope tracking, Laban weight/time/space/flow computation, spin classification, and axial thrust detection logic that was copy-pasted across al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
2026-07-30 firmware: when not connected but on : blue led blink, when connected : blue led on
2026-07-30 JUCE graph: live "Custom" editing, preset viewing, zoom/pan canvas
    - Mapping selector + global volume hoisted above both DSP window tabs
    (MappingSelectorBar), shared instead of Knobs+FFT-only
    - Graph tab now shows the selected mapping's real NodeGraph, auto-laid-out
    by dependency chain; the 11 presets are read-only, "Custom" is fully
    editable and live (thread-safe via a lock in NodeGraph)
    - Canvas: mousewheel zoom, ctrl-drag pan, node/port labels, row-based
    auto-layout with collision avoidance and row-proximity grouping
2026-07-30 JUCE graph: wire removal, param editing, categorized add-node menu
    - Right-click a connection to remove it
    - Double-click a node to edit its param values via a small popup,
    backed by new NodeGraph::setNodeParams
    - Add-node menu split into subcategories (Raw Sensor/Derived Motion,
    Arithmetic/Shaping/Lookup Tables/Dynamics, Scalar/Indexed Array)
2026-07-31 JUCE graph : preset editing and reset button + better layout
2026-08-02 paper: improve 3 points: node count table for presets, sensitivity note on used constants and failure mode note on calibration
2026-08-02 paper: shorter Stage1 failure §
2026-08-02 JUCE: calibration now returns if it fails and ask the user to try again
2026-08-03 JUCE: fix switching mapping bug + fix graph canvas boundarries
2026-08-03 JUCE graph layout: add auto layout button and redo layout algo (still bad)
2026-08-03 hardware: small cleanup and added calibration stand
    [base_print.scad, calibration_stand.scad, calibration_stand.stl]
2026-08-05 JUCE: correct some radians/degree issues
    [NodeMetadata.cpp]
2026-08-06 JUCE preset: spin voice: way simpler : cahnge voice with roll and pitch with pitcj
2026-08-06 paper: add Scope and application, mapping strategy reference and supplementary material
2026-08-12 JUCE: pink noise ! and use it for wind
    [IMappingStrategy.h, NodeMetadata.cpp]
2026-08-13 casing: improve button access
    [base_f.stl, cap_f.stl, case_vscode.scad]
2026-08-13 JUCE: big latency/lock fix
    [IMappingStrategy.h, SynthManager.cpp]
2026-08-17 paper: update pictures and update to current state of the project
2026-08-18 paper avs: add harware wiring
2026-08-19 JUCE: fix preset saving
    [SynthManager.cpp]
